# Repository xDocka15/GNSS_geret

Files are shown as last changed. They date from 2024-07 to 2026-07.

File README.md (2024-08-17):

# GNSS_Geret_V1

[3D model](https://github.com/xDocka15/GNSS_geret/blob/main/V1/3D_Print/stl/board.stl)

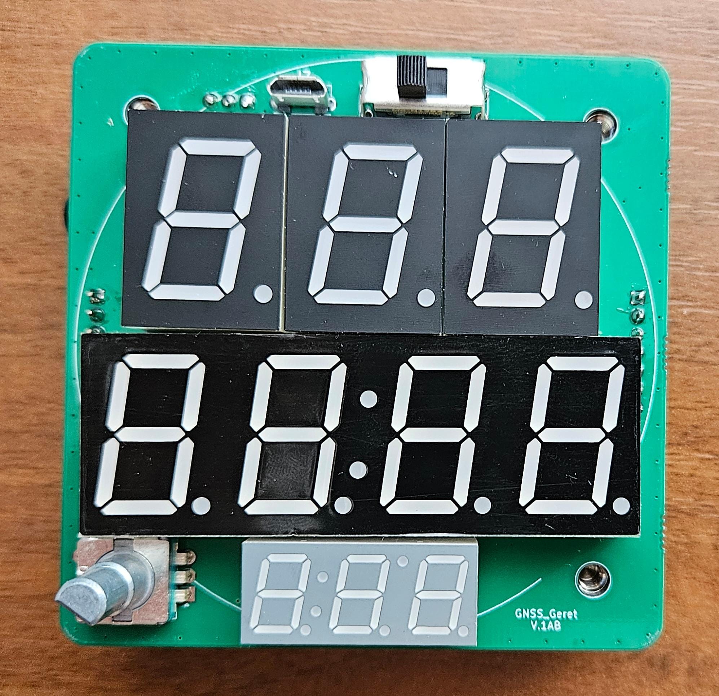
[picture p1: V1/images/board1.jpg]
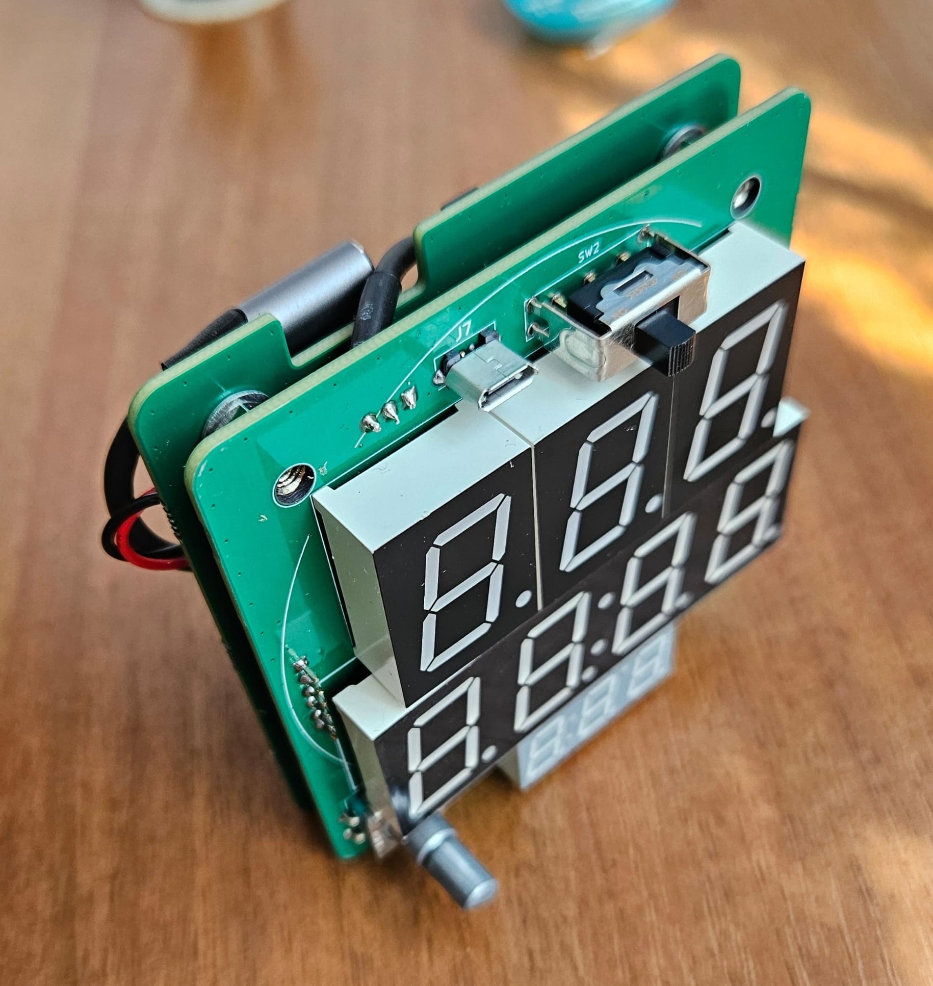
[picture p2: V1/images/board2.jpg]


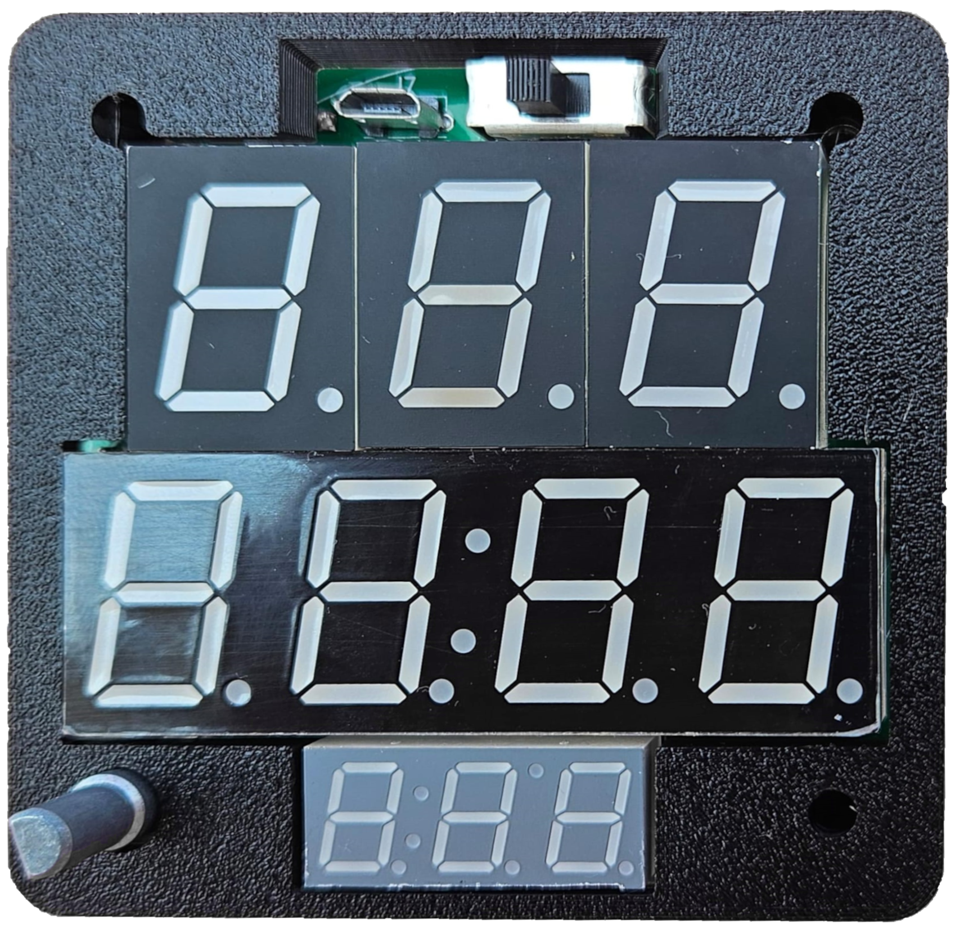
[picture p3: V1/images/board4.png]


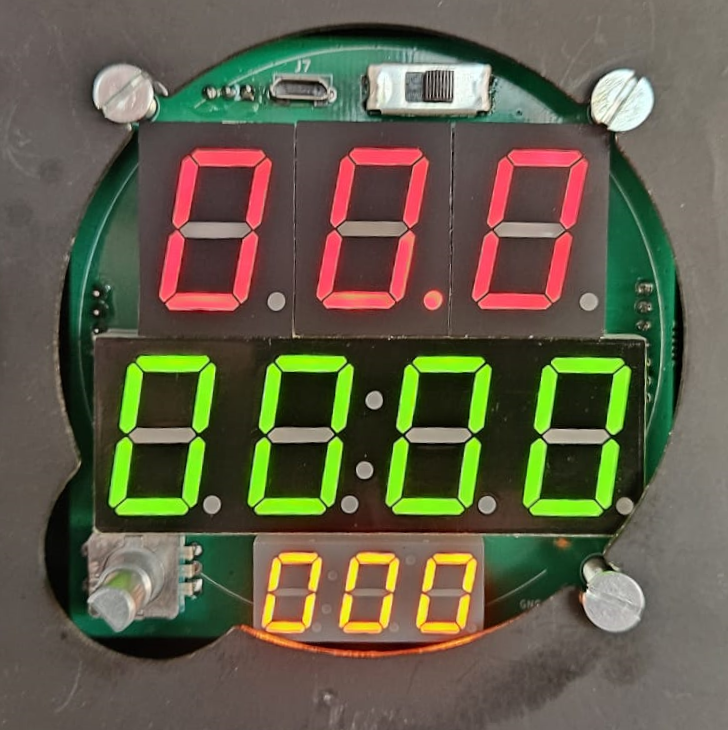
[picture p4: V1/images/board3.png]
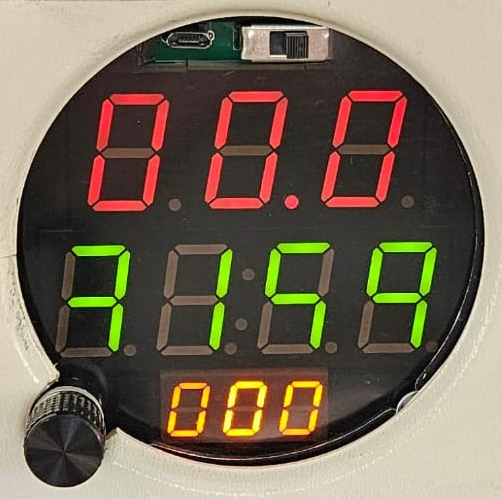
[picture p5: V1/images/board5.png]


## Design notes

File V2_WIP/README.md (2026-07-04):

# Zadanie pre GNSS Geret v2025

Dokument popisuje zmeny/upravy v elektronike gnss-geret z 2024 tak aby vznikla
jednodoskova prenostitelna verzia.

## Strucny opis zmien

Cielom je dosiahnut vyssiu integraciu, mensie rozmery a odstranit nedostatky
z predchadzajucej verzie.

Hlavne zmeny:

* \[x] Z troch DPS zredukovat len na jednu dosku.
* \[X] Povodnu hotovu procesorovu dosku FireBeetle2 nahradit samostatnymi obvodmi
  priamo na DPS a usetrit tym miesto:

  * \[x] Pouzit rovnaky ESP32-WROOM-32E modul
  * \[x] USB/UART prevodnik pre programovanie a ladenie ESP32 aj s DTR+RST pre programovanie
  * \[x] Menic napatia z baterie na 3V3
  * \[x] Nabijaci obvod pre bateriu (lepsi ako na FireBeetle2)

* \[x] Doplnit flash pre zaznam dat.
* \[ ] Lepsia citatelnost displeja s casom.

Vacsina suciastok zostava zachovana, zhodna s verziou v2024.

## Nove suciastky

### ESP32

Zvolit modul:

* ESP32-WROVER-E-N16R8 - trosku vacsi rozmer, ale ma vacsiu pamat, vyvody len z dvoch stran.
* \[x] ESP32-WROOM-32E-N16R2 - mensi rozmer, mensia pamat, vyvody z troch stran.

Umiestnit antenou ku okraju DPS. Pod vstavanou antenou je potrebne odstranit
oblast zeme v jednotlivych vrstvach DPS tak aby nedoslo ku zatieneniu anteny (napr.
vrstvou GND, vid. keepout zone v datasheete). Idealne vyfrezovat z plosaku.

Doska WROVER sa pripajkuje priamo na hlavny DPS.

Nerozpustat obsah WROOM modulu priamo na hlavny DPS, odovodnenie:

* nepredpokladam, ze by sa podarilo dosiahnut vasiu mieru integracie ako samotnemu
  vyrobcovi Espressif - t.j. neusetri sa miesto na DPS
* rucne osadzovanie by bolo skoro nemozne
* vyzadovalo by to ozivit zapojenie aj samotneho procesora
* neskor by ake kolvek chyby mohli mat pricinu bud v osadeni alebo navrhu zapojenia
  procesora

### USB/UART prevodnik

Pouzit niektory z casto pouzivanych USB na UART prevodnikov pre ESP procesory.
Napr. CH340K (bol pouzity aj na FireBeetle2) alebo CP2104, ...

Dolezite je pripojit aj DTR a RTS na GPIO0 a RST aby sa dal procesor uviest do
programovacieho rezimu cez USB.

Inspirovat sa zapojenim podla schemy ku FireBeetle2 alebo napr. ku LiLyGo T-Call.

### SPI Flash

Zapracovat "velku" SPI flash, ktora sa bude pouzivat na zaznam udajov z letu.
Napr. 128Mbit (16MB) [Winbond W25Q128FV](https://www.winbond.com/hq/product/code-storage-flash-memory/serial-nor-flash/?__locale=en&partNo=W25Q128FV).
Pripojit na SPI rozhranie.

* \[x] TODO: vyspecifikovat, na ktore piny procesora pripojit. Ktore z dvoch SPI rozhrani je volne?

### Nabijaci resp. power-management modul

Na napajanie bude pouzity jeden clanok Li-Ion baterie (v letectve sa nepouzivaju Li-Pol).
Mal by obsahovat:

* \[x] moznost vycitat cez komunikaciu (idealne I2C) stav nabijania (miera vybita)
* \[x] coulomb counter na meranie kapacity bateria
* \[x] meranie napatia baterie

Zapracovat modul na sledovanie kapacity LiXy batetie MAX17043.
https://techfun.sk/produkt/max17043-i2c-modul-pre-sledovanie-stavu-baterie-1s/

https://www.sparkfun.com/mikroe-charger-2-click.html
Coulomb counter TC3100 + nabijaci obvod IP5306-I2C.
https://electronics.stackexchange.com/questions/17463/help-on-stc3100-calculations
https://github.com/danirebollo/ArduinoSTC3100

* \[x] TODO: upresnit.

### Tlacidlo

Pridat nove mikro-tlacidlo niekam na pravu prednu stranu.

* \[x] TODO: Vyspecifikovat tlacidlo, umiestnenie a pripojenie.

### Indikacna LED

Pridat SMD modru LED na stranu DPS s displejmi. Pouzije sa na zakladnu indikaciu
a ladenie SW. Spolu s LED na rovnaky ovladaci pin procesora pripojit aj test-pad.
Nakolko su vsetky ostatne LED pripojene len cez komunikacne rozhranie, tato bude
urcite fungovat vzdy.
Zapojit na GPIOxy voci GND.

* \[x] TODO: Urcit, na ktory GPIO pin.

### Senzor osvetlenia

Doplnit senzor osvetlenia a automaticky upravovat jas.
Umiestnit ho do vnutorneho rohu kde sa stretava maly dolny displej a stredny velky displej
na pravej strane (na opacnej ako je encoder, aby sa rukou nezakryl).
V kryte sa na danom mieste urobi vybratie, cez ktore (a cez foliu) bude prenikat okolite svetlo
az ku DPS.

* \[x] TODO: Pouzit jednoduchy fototranzistor? Vyspecifikovat.

## Upravy

Vo verzii v2024 boli na DPS/scheme identifikovane nesledujuce body na zlepsenie:

* \[x] Doplnit USB iface pre gnss (3v3 urovne, pripojit vdd\_usb)
  Zvazit umiestnenie plnohodnotneho USB micro-B konektora otoceneho ku okraju DPS
  kvoli servisnemu pristupu do GNSS modulu. Pouzit uhlovy konektor o 90st zarovnany
  s okrajom DPS. Pristupny bude len po vybrati DPS z krabicky.
* \[x] Pridat odrusovaci kondik na tlacidlo tocitka.

  * TODO: Vyspecifikovat.

* \[x] Na vstup A a B z encodra doplnit pull-up rezistory 10k na 3V3.
* \[x] Do footprintu encodera pridat aj diery pre upevnovacie otvory (pajkovatelne, spojene s GND)
* \[x] Pouzit iny typ stredneho 4-ciferneho displeja:

  * Na v2024 bol pouzity typ so spolocnou anodou (KW4-804AGB).

    * Radic HT16K33 je koncipovany tak, ze:
    * cez samostatne anody dokaze do LED pustit 20mA
    * ces spolocnu katodu dokaze preniest 8x 20mA
    * kvoli tomu nebolo mozne vybudit LED na maximalny jas co sa prejavilo na zlej
      citatelnosti za slnecneho svetla.

  * \[x] Vo v2025 pouzit model so spolocnou katodou (KW4-804CGB).

    * Tomu sa musi prisposobit aj zapojenie jednotlivych segmentov (po vzore maleho displeja).
    * \[x] TODO: vyspecifikovat zapojenie displeja.

* \[x] Pouzit USB-C konektor, zapojenie rovnake ako na FireBeetle2.
* \[x] Ku GNSS modulu pripojit aj zalohovaciu bateriu pre RTC.

### Chybajuce veci

Vo verzii v2024 chybali nasledujuce veci, ktore su aplikovatelne aj na v2025:

* \[x] Na 5V vetvu pridat velky stabilizacny kondik 470u/16V.
* Doplnit oznacenie D2 do schemy.
* \[x] Pridat test pad s GND (na pripojenie sondy multimetra/osciloskopu).

### Navrh DPS

Pri navrhu DPS zohladnit nasledujuce pripomienky:

* \[x] Pri ploskach spojenych s GND nastavit uzsie (tensie) mostiky, ktore prepajaju
  plosku s okolitou "vyliatou" plochou, resp. s vrstvou GND. Pri rucnom pajkovani
  sa cez mensie mostiky odvadza menej tepla do susednej velkej medenej plochy
  a suciastky sa lahsie osadzuju.
* \[x] Popisok konektora dat dalej od samotnej suciastky (aby sa po osadeni nezakryl).
* \[x] Zvacsit diery pre hlavny vypinac (bolo treba zbrusit z pinov).

  * \[x] TODO: diery pre kontakty alebo upevnovacie diery?

* \[x] Mensie diery pre kolikove konektory (ak budu pouzite, boli volne a dali sa osadit krivo :)
* \[x] Doplnit popisky ku test-padom "TPx" aby sa dali lahsie sparovat so schemou.
* \[ ] Pri vyrobe pouzit ciernu farbu plosaku, nie zelenu. Cierne pozadie zlepsi
  citatelnost 7-seg displejov.
* \[x] Niektore TP presunut ku okrajom DPS, tak aby boli dostupne z oboch stran DPS
  a neboli zakryte suciastkami (napr. displejmi):

  * TP6 (5V)
  * TPxy (3V3, pridat)
  * TPxy (GND, pridat)

* \[x] Antenny konektor moze byt bud SMA alebo U.FL (IPEX)

  * Na DPS cez seba prekryt plosky pre oba typy konektorov
  * Vid. footprint: https://meshtastic.org/assets/images/t-beam-sx1262-3dc0a8d2d866b06b04a457567063e034.webp
  * Bud sa osadi SMA konektor (uhlovy alebo priamy) alebo sa osadi U.FL konektor
    a antena sa zabuduje priamo do skatulky.

* Pri rozmiestnovani suciastok je mozne umiestnit niektore aj pod maly dolny
  displej z TOP strany.

  * Aby bol displej v rovine s RGB displejmi, musi byt osadeny co najdalej od DPS.
  * Tym vznikne pod displejom pohodlny priestor pre SMD rezistory, kondiky, atp...

    * \[ ] TODO: zmerat vzdialenost od DPS po display.

## Mechanicke upravy

* Zachovat rozostup aj velkosti montaznych dier v troch rohoch.

  * Pouziju sa bud na uchytenie do pristrojoveho panela v lietadle alebo na
    uchytenie krabicky.

* Ine montazne diery nebudu potrebne. Bateria sa osadi do drziaka v krabicke.
* Zachovat umiestnenie antenneho konektora GPS na okraji plosaku aby sa mohol
  pouzit aj uhlovy konektor a externa antena.

# Pripomienky k v2024

Releventnost nasledujuce pripomienok ku verzii v2024 a ich aplikovatelnost aj na
verziu v2025 treba posudit jednotlivo. Niektore mozu byt pouzite aspon ako inspiracia
pre finalnu kontrolu DPS pred odoslanim do vyroby.

* Chyba popisok "U8" pre prislusnu suciastku na DPS
* Popisky DP a DM na J3 nie su rovnakym smerom
* Roztec ESP pinheaderov je mala, nesuhlasi s ESP doskou. Zapichnuta kolikova lista
  sa roztiahne ako vejar.
* nejednoznacne ozn. pre D a C (co som tym myslel?)
* kvoli zahnutemu kablu USB-C na ESP doske posunut ESP dosku o 7mm do lava
  a presunut J4 dole na uroven RST tlacitka (na ESP doske)
  a otocit orientaciu J4 smerom hore
* USB konektor pre GNSS dat dalej od ANT1 kvoli pristupu.

# Poznamky/Uvahy

* \[ ] V pripade zabudovania v lietadle a pripojenia ku palubnej sieti bude potrebny
  dodatocny obvod s:

  * menicom napatia z 12/24V na 5V
  * elektronickou poistkou

# Pripomienky k v2026

# pripomienky/navrhy

**26.6.2026**
Telefonicky konzultovane pripomienky: 

- [x] Upgradovat projekt na KiCAD v10?
- [x] Doplnit barometer na I2C linku 
  - https://eu.mouser.com/ProductDetail/Bosch-Sensortec/BMP581?qs=Li%252BoUPsLEntPL9tlFmcgXg%3D%3D
  - umiestnit na top stranu medzi encoder a maly display (do stredu aby bolo dost miesta na teplovzdusne osadenie)
  - CSB pripojit priamo na VDDIO (zvolit I2C)
  - SDO pripojit na GND
  - INT zapojit na TestPad
  - treba zaradit 10Ohm odpor do serie s VDD a VDDIO?
- [x] Na spolocne katody oboch 7seg displejov DS1 (CC1, CC2, CC3, CCL123) a U402 (CC11, CC22. CC33, CC44) doplnit 0Ohm odpor 0603 (mozno sa pouzije na zrovnanie intenzity stredneho a dolneho 7seg displeja, kedze zdielaju jeden driver a spolocne ovladanie intenzity)
- [x] Zvazit otocenie U103 o 90st v proti smere hodinovych ruciciek (bodka bude hore v pravo, Y+ bude smerovat hore)
  - len ak to nebude prilis komplikovane, je mozne kompenzovat smer osi v SW
- [x] Flash U102 zamenit za iny model a ine puzdro, napajanie 2.7-3.3V: 
  - pouzit male puzdro WSON-8 8x6mm (velkostou sa zhoduje s SOIC8 povodne pouzitej W25Q128JV)
    - Winbond W25N02KVZEIR 2Gb (256MB) (Mouser ma na sklade):
      - https://eu.mouser.com/ProductDetail/Winbond/W25N02KVZEIR-TR?qs=YwPsRIUVAOcmpACOC6b95Q%3D%3D
    - Winbond W25N04KVZEIR 4Gb (512MB) (Mouser nema na sklade) 
      - https://eu.mouser.com/ProductDetail/Winbond/W25N04KVZEIR?qs=YwPsRIUVAOdveyibmg1m8Q%3D%3D
  - existuje aj velke SOIC16 puzdro (s dobrou dostupnostou na Mousri) ale to je prilis objemne:
    - https://eu.mouser.com/ProductDetail/Winbond/W25N02KVSFIR?qs=W%2FMpXkg%252BdQ4KUHHgPqoidQ%3D%3D
    - W25N02KVSFIR 2Gb
    - zmesti sa na miesto povodne SOIC8 ak by sa posunul U103 hore?
    - existuje aj mensia kapacita 1Gb: W25N01GVSFIG
- [x] U602 GND pripojit najskor ku R_E605 a az potom ku GND vrstve, vid AppNote strana 4: The STC3100's ground connection (GND) is used as the reference input for the current measurement and must be connected to the ground side of the sense resistor by a dedicated track.
- [x] Ku R_E605 doplnit poznamku, ze jeho hodnota musi splnat: `Rcg <= 0.08/peak_current_A` a `33mOhm => peak +/-2A`.
- [x] U602 pripojit natrvalo ku baterii. Vypinac dat az za U602. 
  - [x] VIN pripojit priamo na bateriu (aj s filtrom).
  - [x] Doplnit SMD jumper, ktorym sa VCC pripoji bud na VIN (pred vypinacom) alebo na BATT (za spinacom)
    - NIE, VCC bude pripojeny stale na bateriu pred vypinacom aby sa zachoval obsah internej RAM
  - Odber obvodu je len 100uA, bude udrzovat stav pocitadiel v internej RAM aj pri vypnutom ESP co zjednodusi sw.
- [x] Nastavit inu I2C adresu pre display driver U4 
  - signaly A0,A1,A2 (ROW2-0) pripojit cez odpory 39kOhm a cez jednu spolocnu diodu ku pinu AD (COM0), vid datasheet
  - jeden z odporov sa osadi tak aby sa zabranilo kolizii adries s CoulombCounterom
- [x] Ku R_E601 pridat TestPad na stranu ku pinu KEY
- GPS U401: 
  - VDD_USB je pouzite nie na napajanie ale na zistenie pritomnosti USB, musi byt urovne 3V3, odber je cca 1mA
  - [x] Pridat jednosmerny level shifter z 5V na 3V3, ktory sa pripoji na VDD_USB cez pull down rezistor 10kOhm + 1uF kondenzator 
    - Alebo pouzit LDO tak ako na vzorovej GNSS7CLICK doske (AP7331)
  - [x] do serie s USB_DP/M pridat rezistor 27 Ω 5% 0.1W (vid vzor GNSS7CLICK)
  - [x] 1uF kondenzator hned vedla VCC pinu
  - skontrolovat layout DPS pre VCC pin a RF_IN pin podla NEO-M9N_Integrationmanual_UBX-19014286.pdf strana 81 https://content.u-blox.com/sites/default/files/NEO-M9N_Integrationmanual_UBX-19014286.pdf
  - [x] EXTINT vytiahnut na TestPad
  - [x] pin Reset vytiahnut na TestPad
- [x] Su niekde v plosaku "slepe prekovy"? T.j. take co nejdu napriec celym plosakom ale len od vonkajsej po niektoru vnutornu vrstvu? 
  - Nemali by sme mat, predrazilo a skomplikovalo by to vyrobu. Na nasom plosaku by sa tomu malo dat vyhnut.
  - NIE, KiCad taketo prepoje by default nerobi
- [x] Prekovy v ploskach urcenych pre rucne osadzovanie sa daju prezit. Ale pri strojovom osadzovani by do nich vtahovalo cin a potom by nozicka nebola pripajkovana (skusenosti z roboty). Idealne ak by prekovy boli mimo padov - aspon pre sucsiastky, ktore maju potencial na strojove osadzovanie (t.j. tie, ktore sa tazko osadzuju rucne).
  - Pokusit sa presunut prekovenia tam kde sa to da. Pri zvysnych prekovoch sa spolahneme, ze sa pri vyrobe PCB (cez JLC PCB) upchaju diery a nebudu stahovat cin.
- [x] Prekovy mimo pajkovacich ploch prekryt nepajivou maskou (farbou). Hlavne tie, ktore su blizko pajkovatelnych ploch (aby do nich nevtahovalo cin a suciastku)
  - KiCad to tak robi by default
- Doplnit menic z externeho zdroja 12-30V na 5V/3A 
  - Externe napajanie bude privedene cez konektor, asi cez Zeleny Konektor - este upresnit !!!
- [x] Ku TP7 doplnit popisok "3V3"
- [x] Ku TP103 doplnit popisok "5V"
- [x] Odstranit popisok "+5V" pri C406
- [x] Doplnit popisky s vyznamom LED: D101 "3V3", D102:"5V", D103:"VUSB"
- [x] Do schemy ku jednotlivym IO z ESP doplnit popisok s vyznamom: (podobne ako tam uz je SCK, MOSI, ...) 
  - IO0: RTS
  - IO2: LED
  - IO4: SEL_FL
  - IO12: TP12
  - IO13: RGB_DATA
  - IO14: PULSE
  - IO15: SW2
  - IO16: GNSS TX
  - IO17: GNSS RX
  - IO25: ENC SW
  - IO26: ENC CLK
  - IO27: ENC DT
  - IO32: SEL_IMU
  - IO35: LIGHT_SENS
- [x] Ku R_E605 doplnit "1%"
- [ ] Ku J601 doplnit typ konektora (PH2.0?)
  - zistit typ podla konektora na baterii
- [x] Doplnit externy PullUp rezistor na IO5 (vyber modu pri bootovani)
- [x] Kozmeticke upravy v scheme: 
  - Strana6: Premiestnit odkaz na USB a BATT na najblizsiu krizovatku cesticiek s bodkou
- [x] Ku kazdemu I2C cipu pridat jeho adresu:
  - `0xEA` BatteryCharger
  - `0x70` CoulombCounter
  - `0x71-7` DisplayDriver, nastavuje sa cez ROW0-2
  - `0x46` Baro
  - `0x44` Lux meter
  - `0x14` Magnetometer
- [x] Vsade na DPS doplnit popisky s oznacenim (nazvom) suciastok
- [x] Doplnit snimac svetla na I2C zbernicu OPT3001 alebo OPT3004DTSR (package SOT-5X3)
  - umiestnit blizko fotorezistora
  - pin ADDR pripojit na GND
- [x] Overit, ci staci 600mA na 3V3 pre ESP aj GNSS aj ostatne obvody?
  - Na prvom gerete bol rovnaky zdroj 600mA
  - Pribudli nove obvody (baro, flash, imu, magnetometer)
- Vymenit nabijaci cip za USBC-PD, ktory poskytuje nabijanie 1S LiXX clanku

# Dokoncit:

- ???

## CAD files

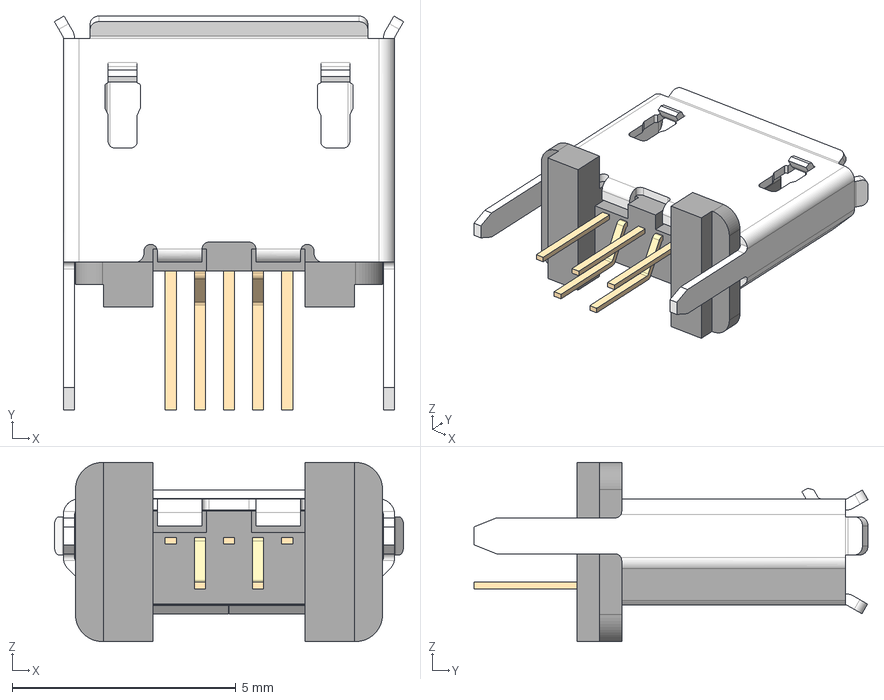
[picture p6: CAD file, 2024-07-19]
V2_WIP/3D/LIB_USB3145-30-1-A/USB3145-30-1-A/3D/USB3145-30-1-A.stp
7.80 x 8.80 x 4.00 mm
USB3145-30-1-A_PART7
USB3145-30-1-A_PART6
USB3145-30-1-A_PART5
USB3145-30-1-A_PART4
USB3145-30-1-A_PART3
USB3145-30-1-A_PART2
USB3145-30-1-A_PART1

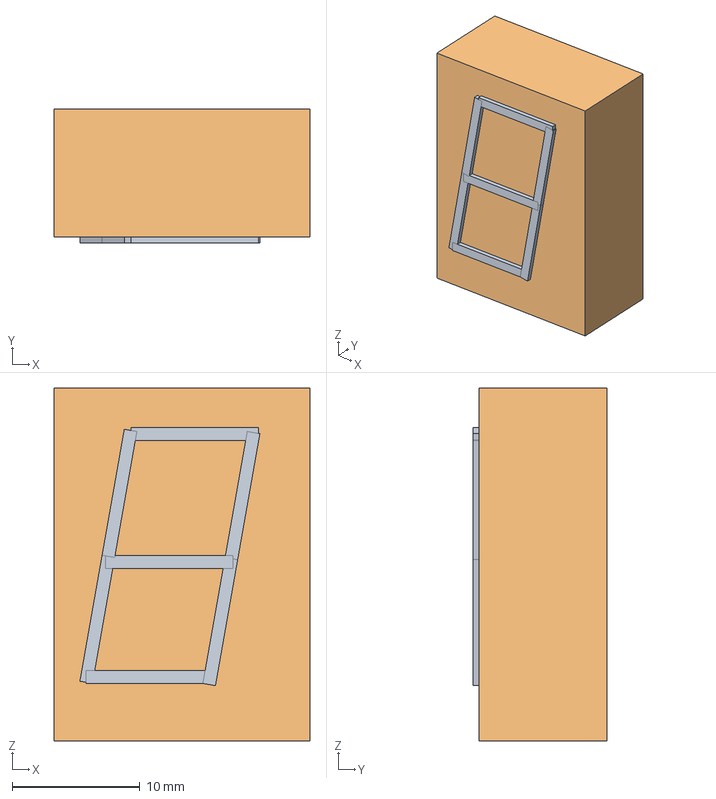
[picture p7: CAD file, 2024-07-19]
V2_WIP/3D/RGB-7seg.step
20.0 x 10.5 x 27.6 mm

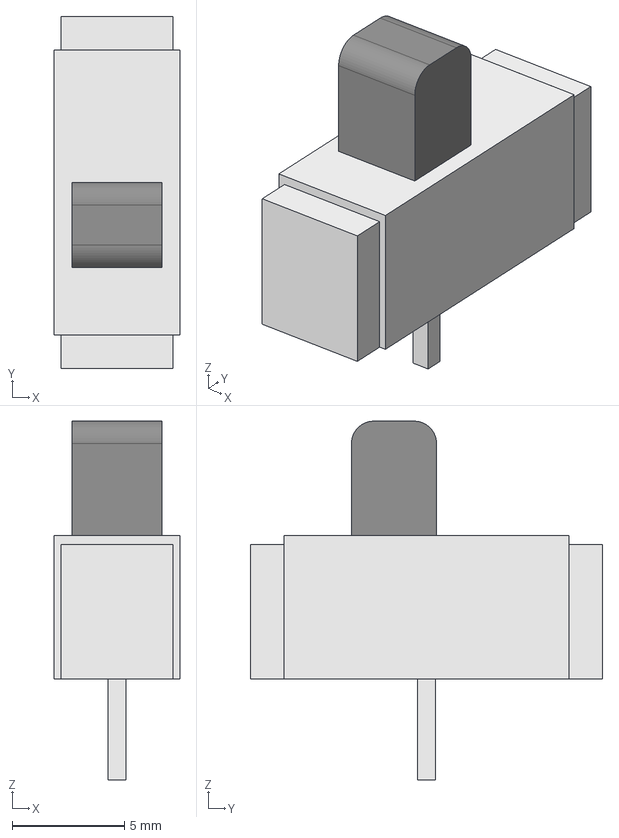
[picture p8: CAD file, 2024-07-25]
V2_WIP/3D/Switch/Switch.step
5.60 x 15.7 x 16.0 mm

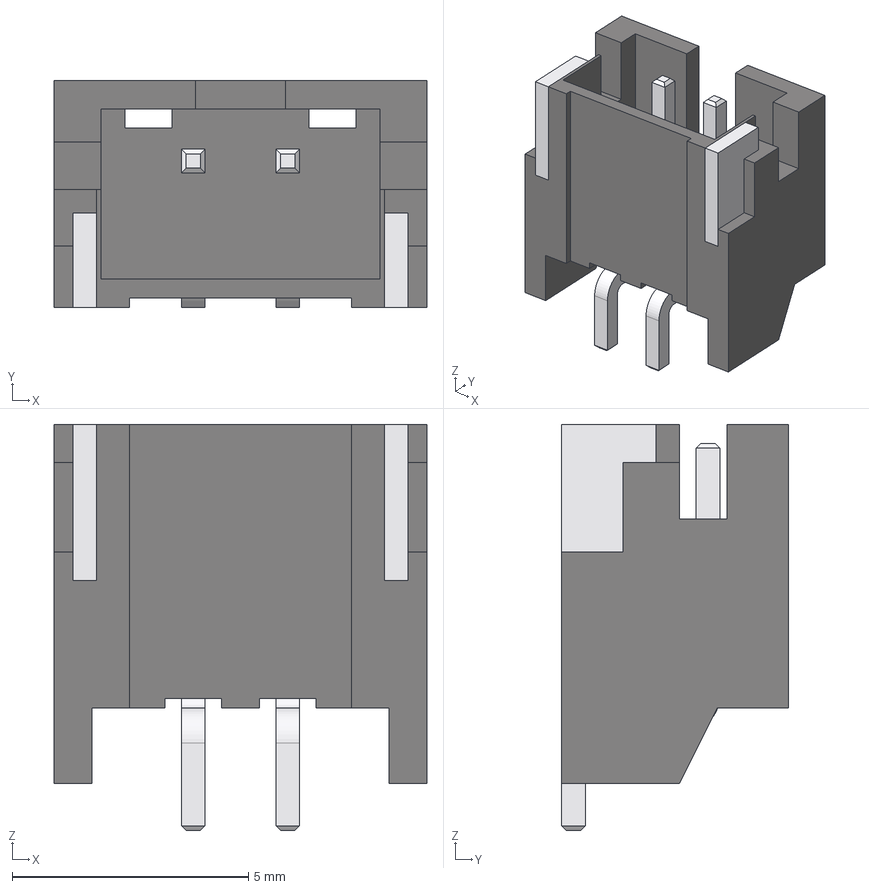
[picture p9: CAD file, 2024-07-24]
V2_WIP/footprints/LIB_1769/1769/3D/1769.stp
7.90 x 4.80 x 8.60 mm

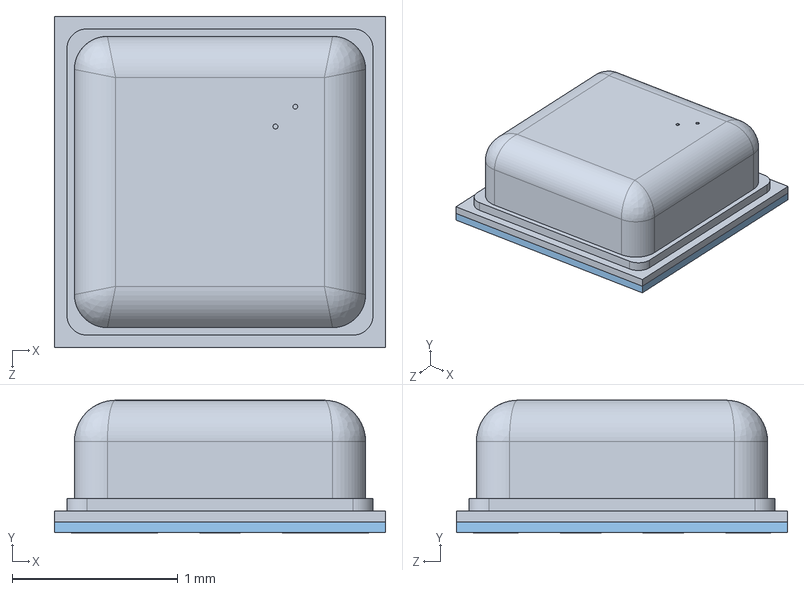
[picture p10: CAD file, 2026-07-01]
V2_WIP/footprints/LIB_BMP581/3D/BMP581.stp
2.00 x 0.801 x 2.00 mm

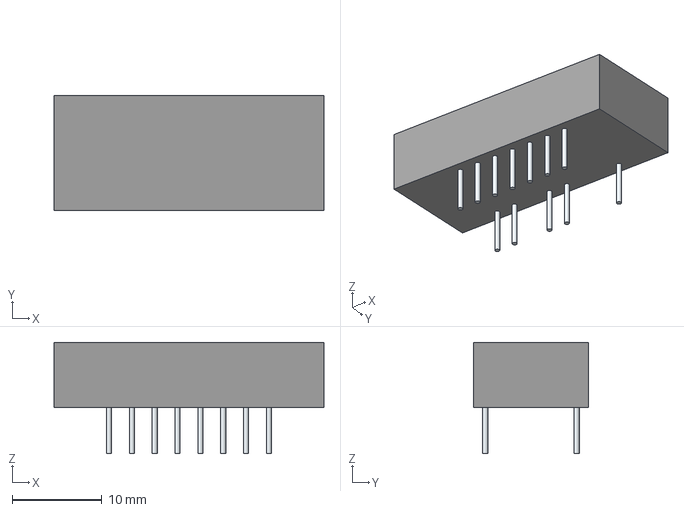
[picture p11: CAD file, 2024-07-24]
V2_WIP/footprints/LIB_LTC-4724JF/LTC-4724JF/3D/LTC-4724JF.stp
30.0 x 12.8 x 12.3 mm
Leads

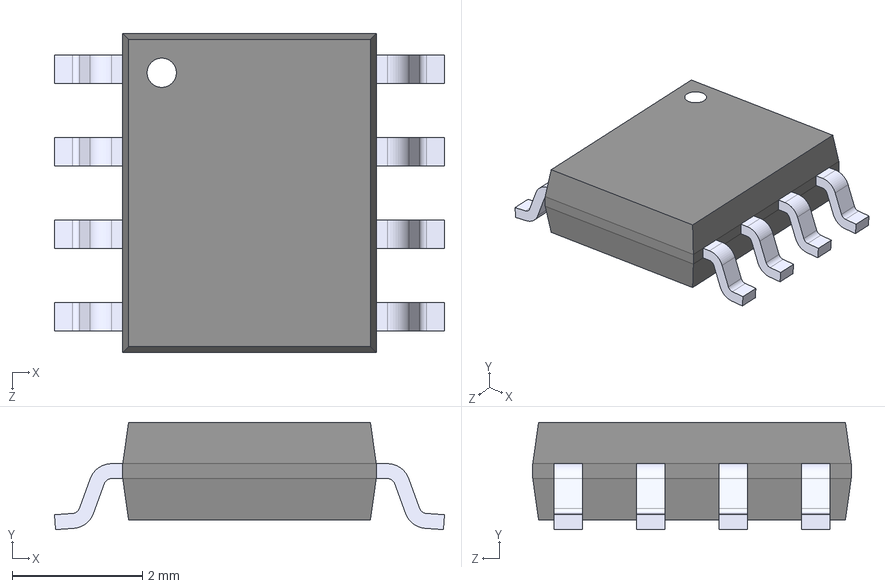
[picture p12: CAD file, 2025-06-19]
V2_WIP/symbols/IP5306/IP5306.step
6.00 x 1.65 x 4.90 mm

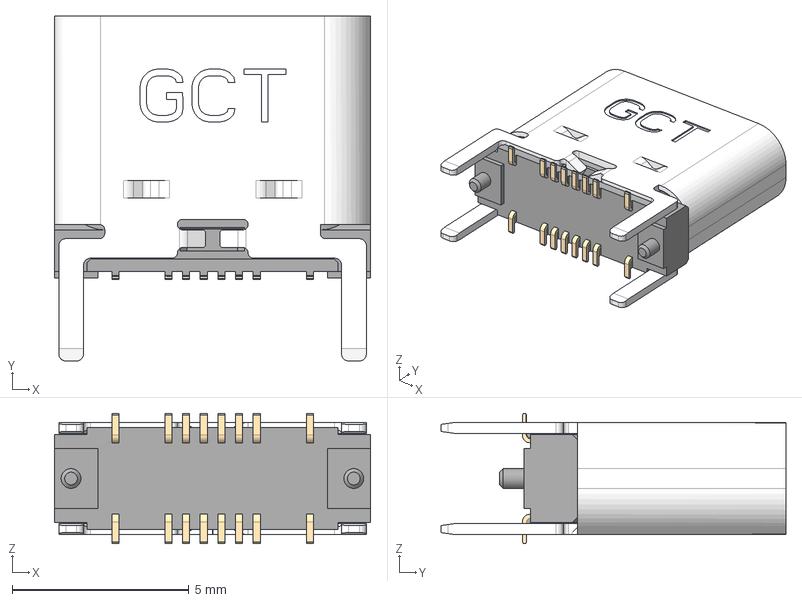
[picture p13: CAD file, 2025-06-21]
V2_WIP/symbols/LIB_USB4145-03-0230-C/USB4145-03-0230-C/3D/USB4145-03-0230-C.stp
8.95 x 9.76 x 3.69 mm
USB4145-03-0230-C_PART2
USB4145-03-0230-C_PART1

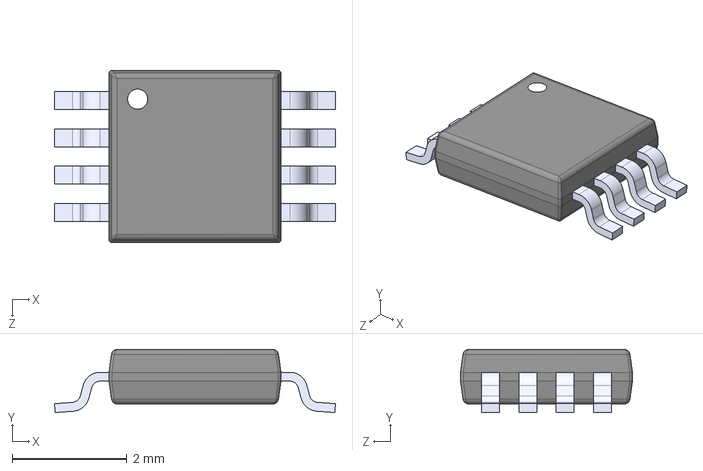
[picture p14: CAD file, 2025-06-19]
V2_WIP/symbols/STC3100IST/STC3100IST.step
4.90 x 1.10 x 3.00 mm

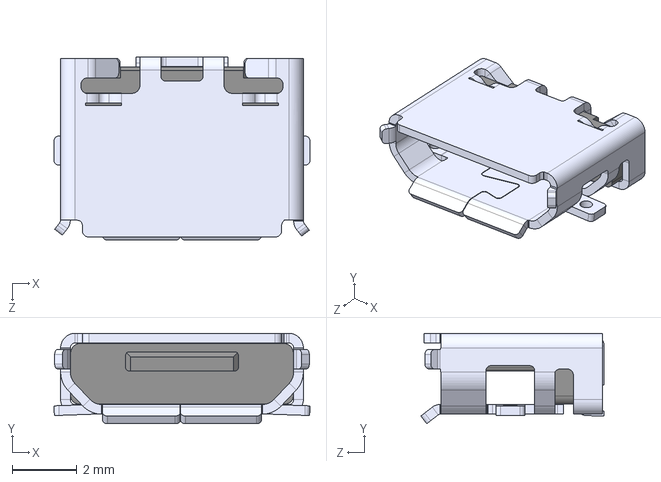
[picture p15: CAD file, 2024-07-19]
V2_WIP/3D/10118192-0001LF/10118192-0001LF.step
7.91 x 2.79 x 5.67 mm

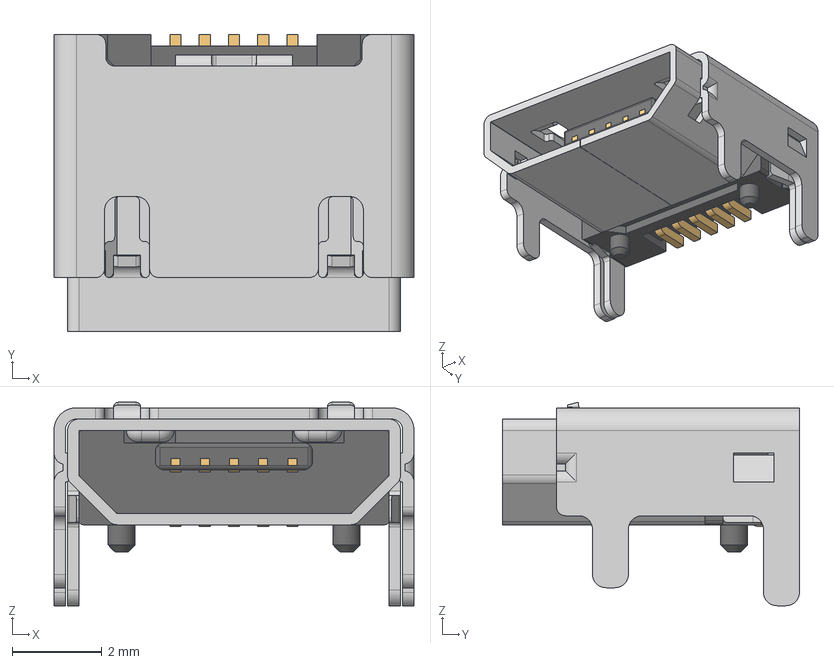
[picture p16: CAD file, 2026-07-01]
V2_WIP/footprints/LIB_629105150521/629105150521/3D/629105150521.stp
8.00 x 6.60 x 4.52 mm
629105150521_Housing
629105150521_Pin1 x 4
629105150521_Pin2
629105150521_Shielding2
629105150521_Shielding

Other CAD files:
V2_WIP/3D/RGB-7seg.FCStd
V2_WIP/3D/Switch/Switch.FCStd

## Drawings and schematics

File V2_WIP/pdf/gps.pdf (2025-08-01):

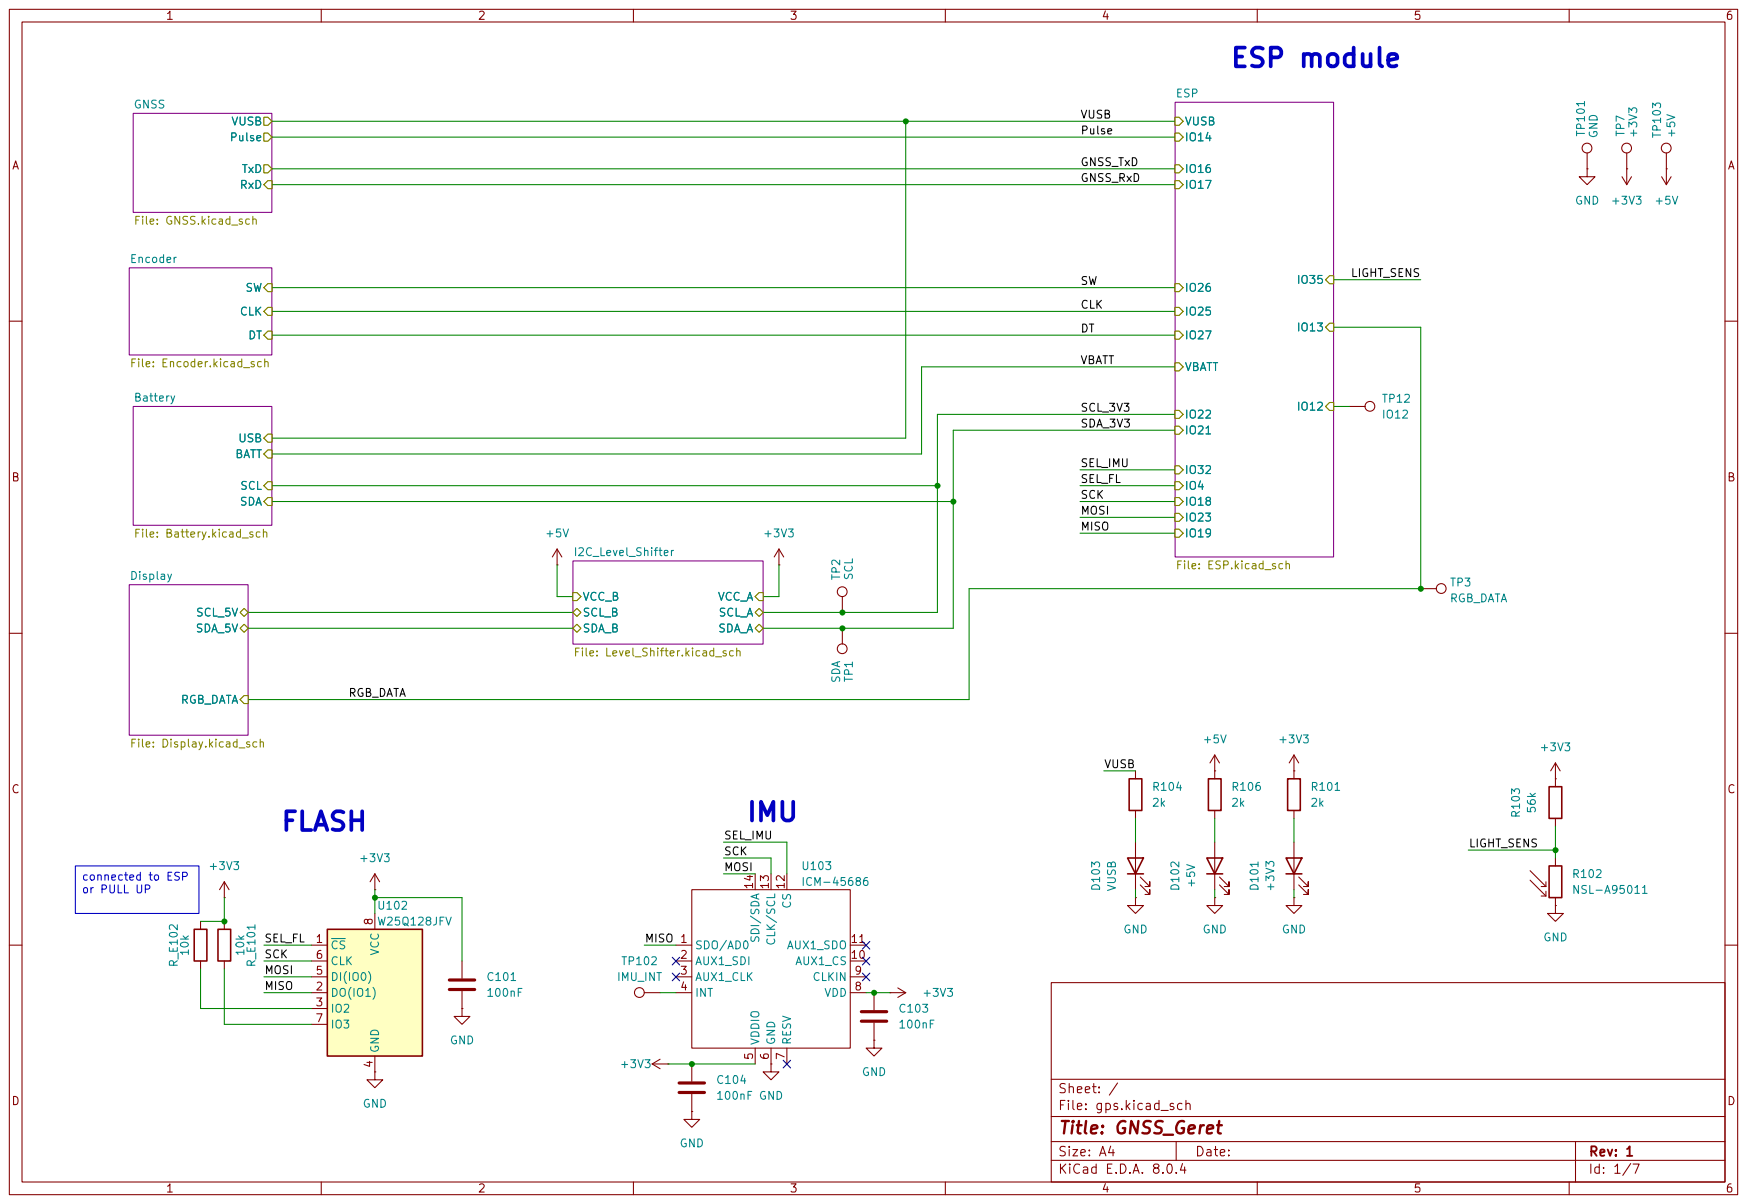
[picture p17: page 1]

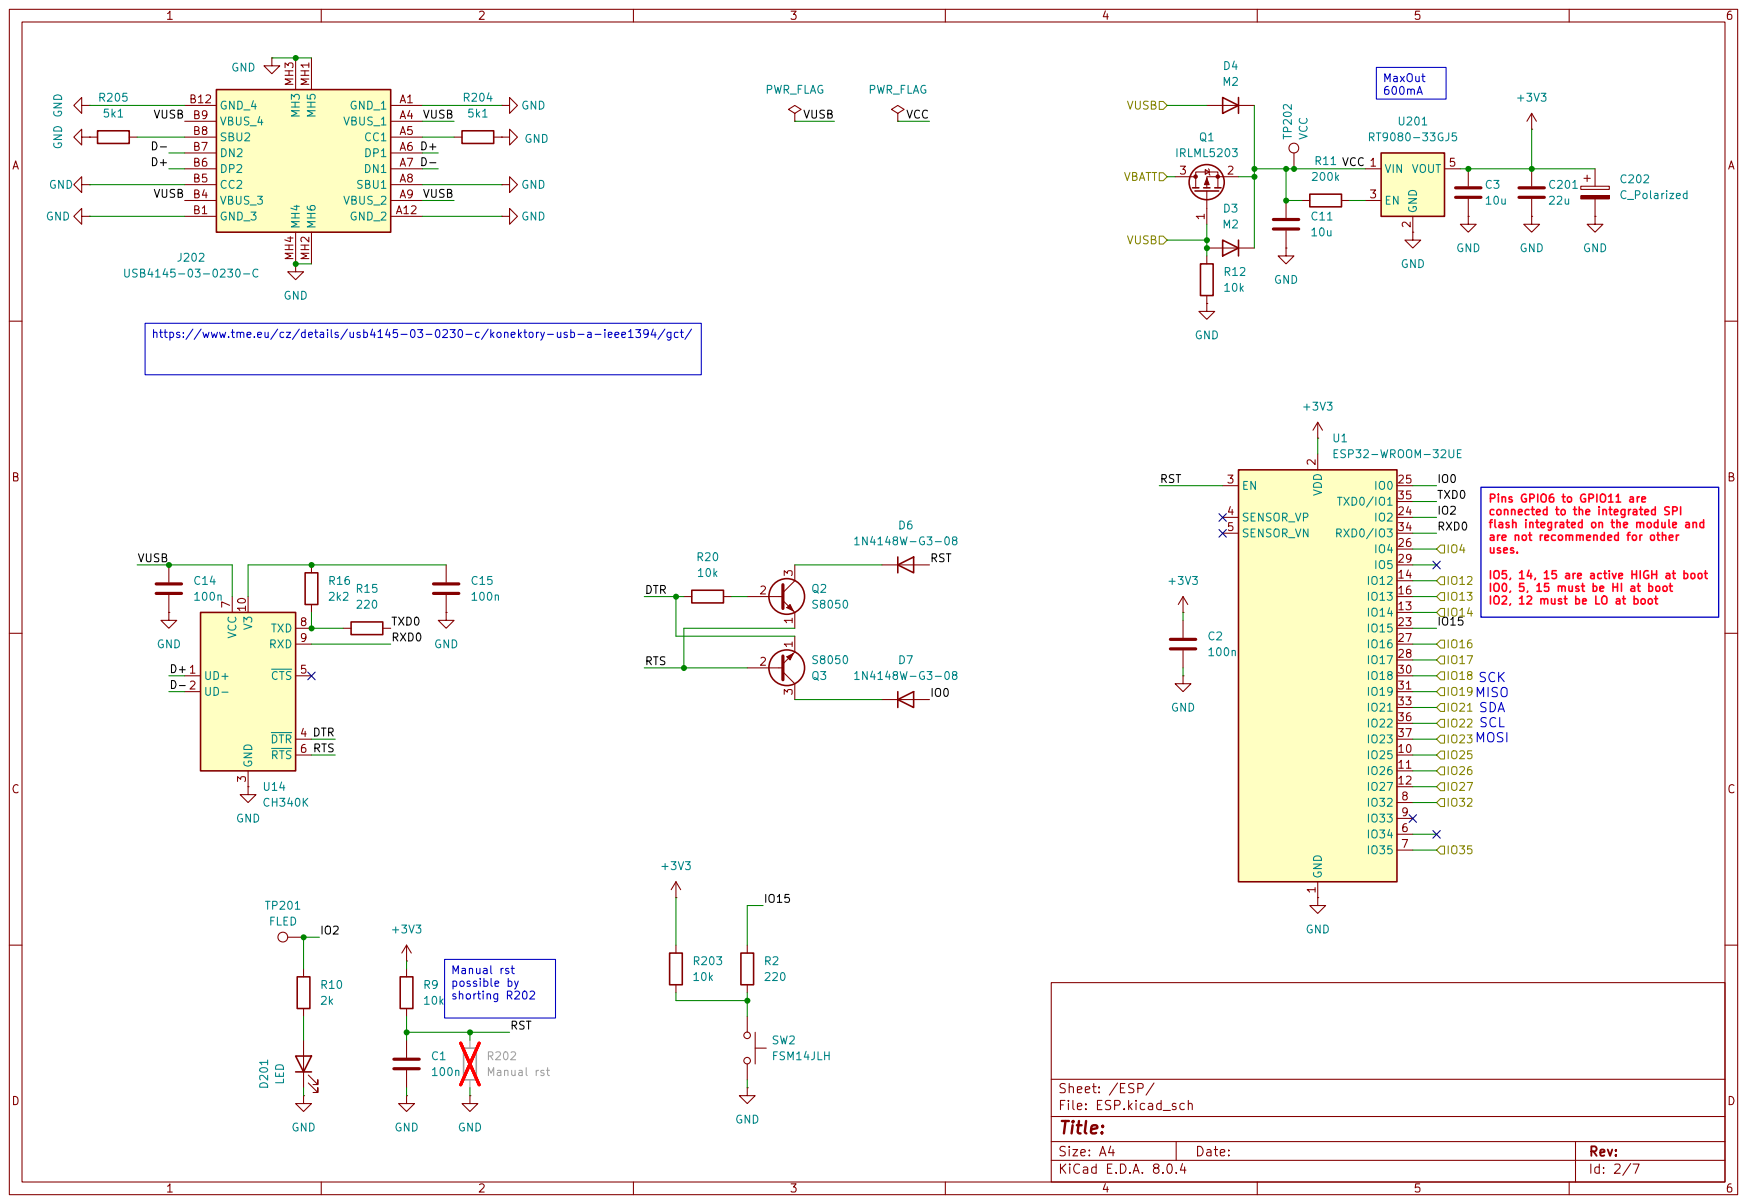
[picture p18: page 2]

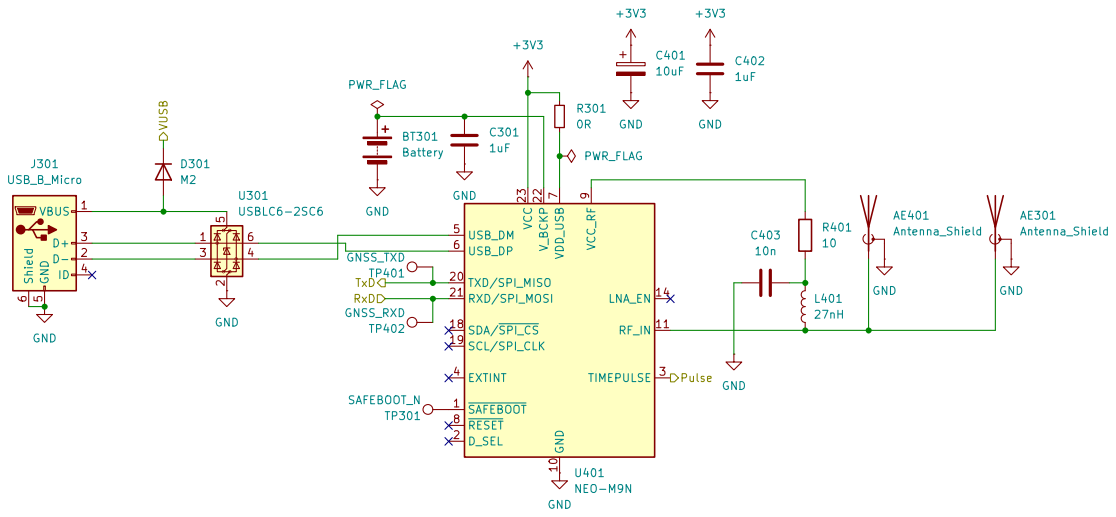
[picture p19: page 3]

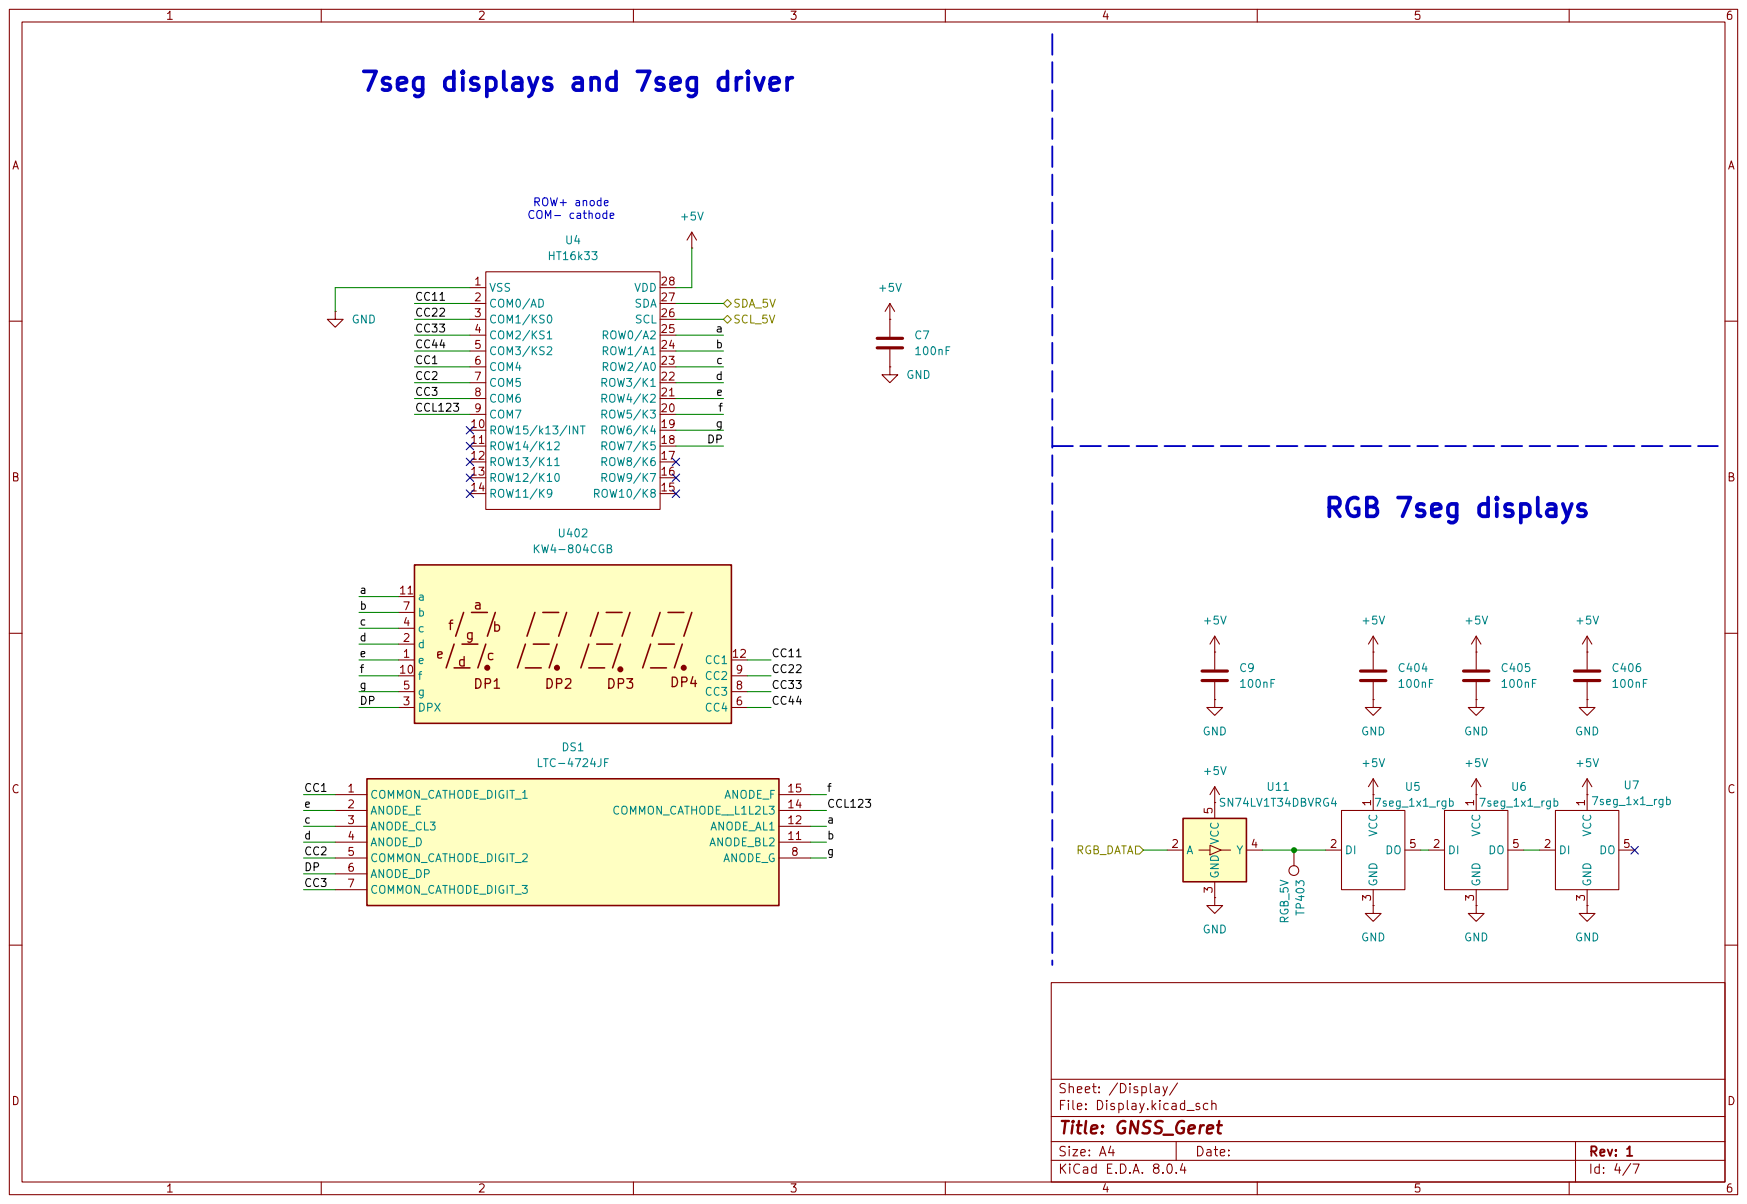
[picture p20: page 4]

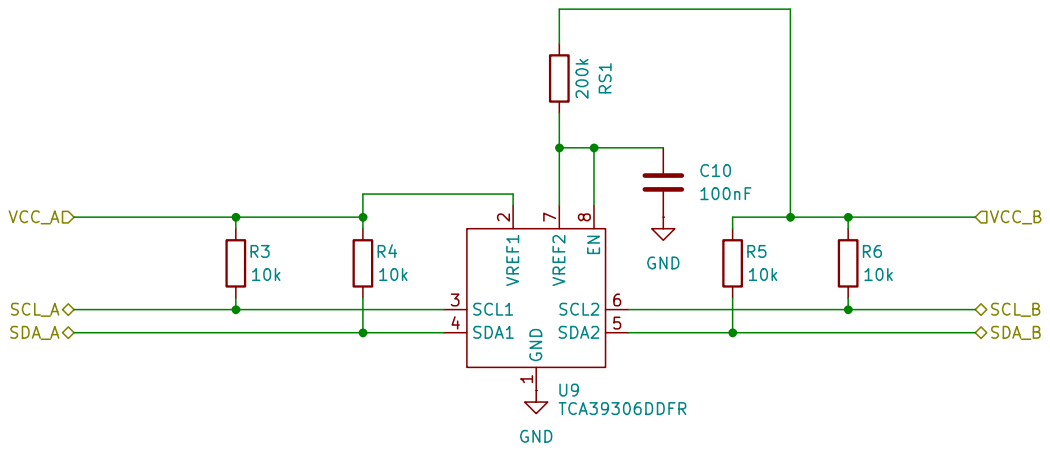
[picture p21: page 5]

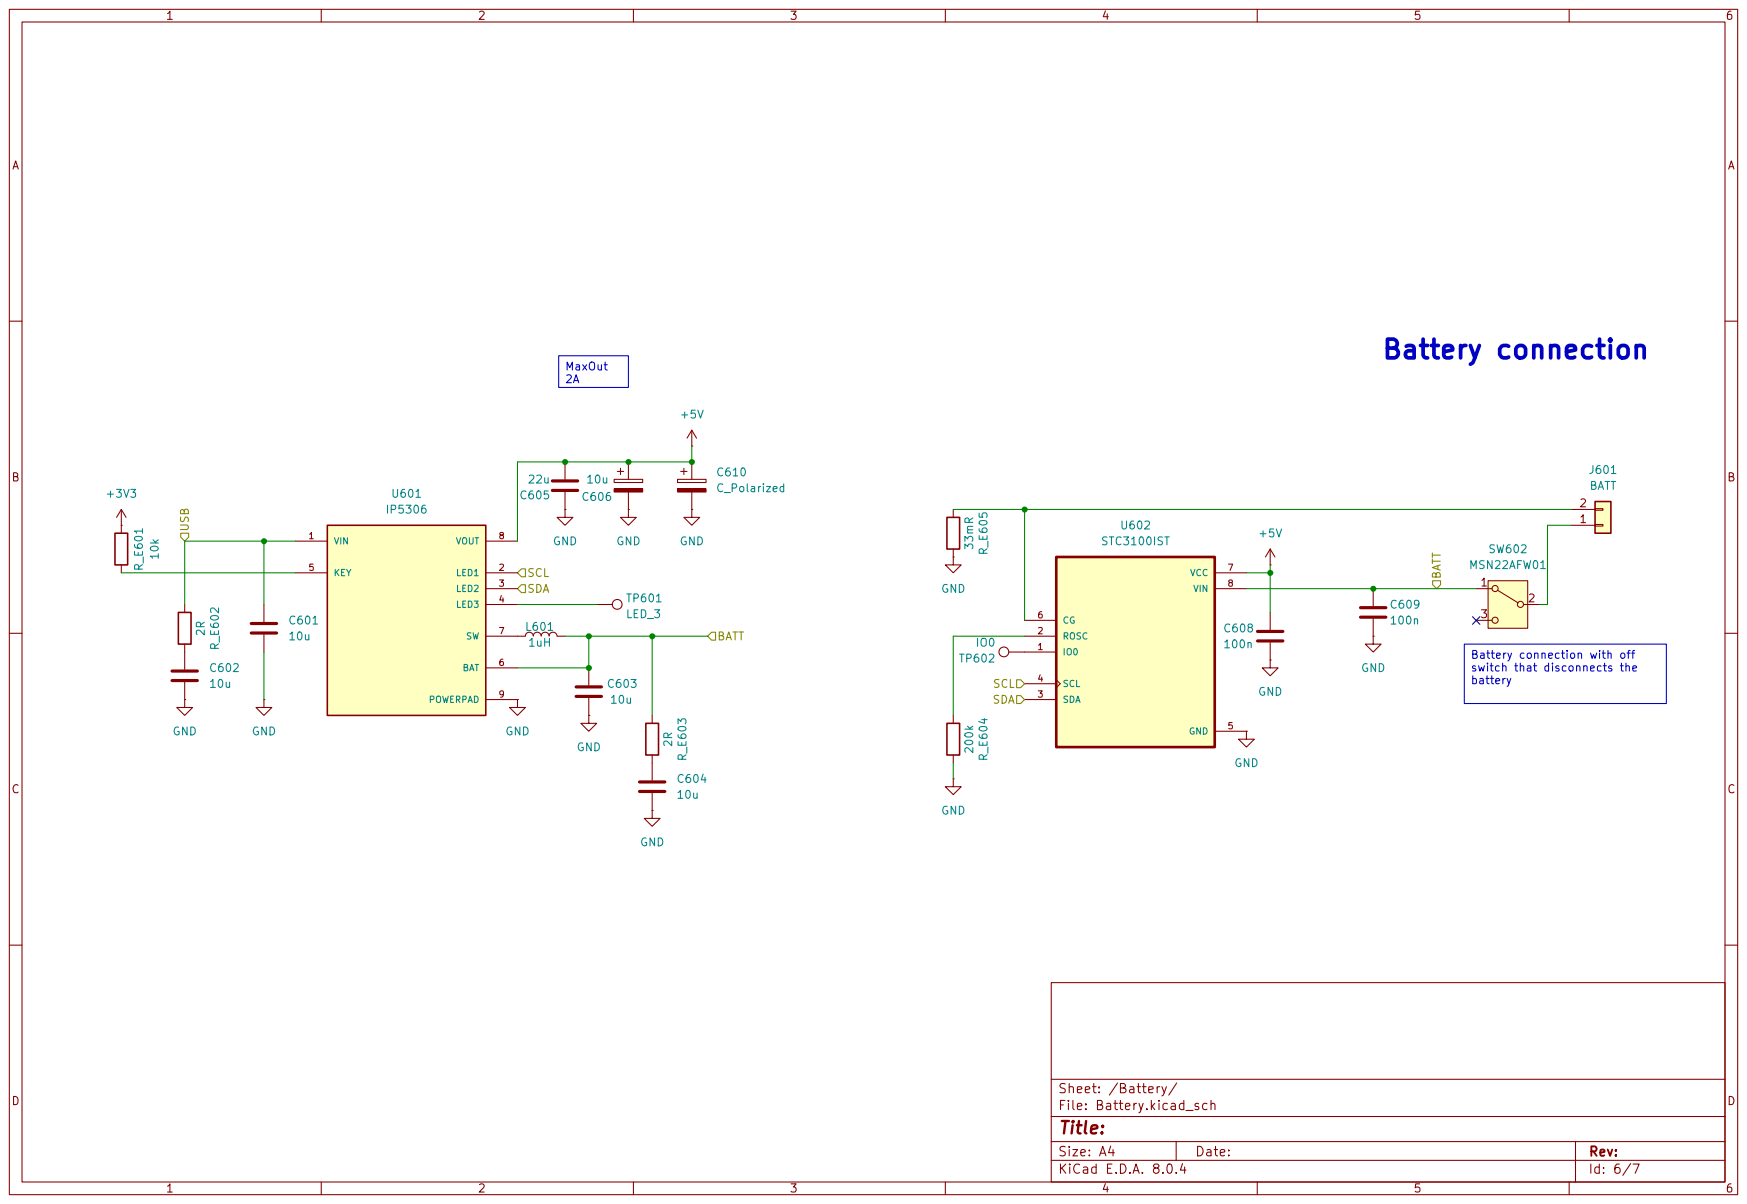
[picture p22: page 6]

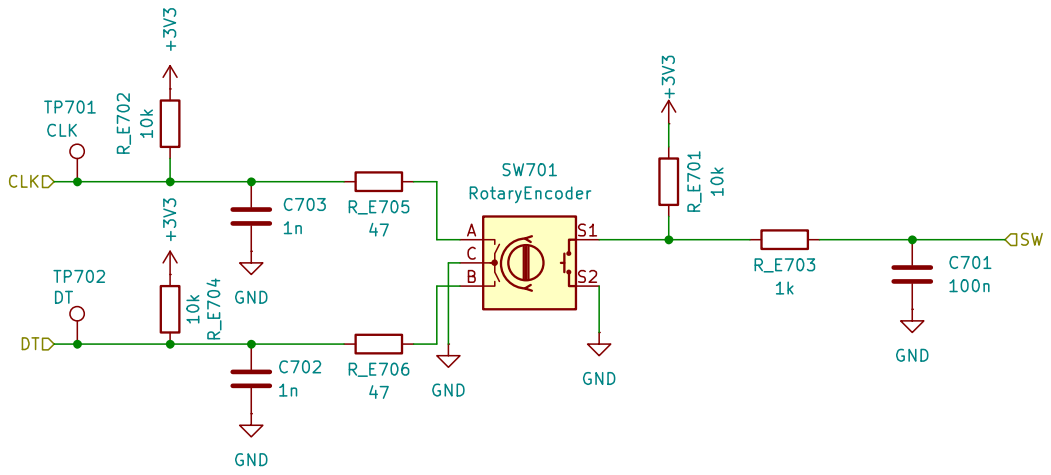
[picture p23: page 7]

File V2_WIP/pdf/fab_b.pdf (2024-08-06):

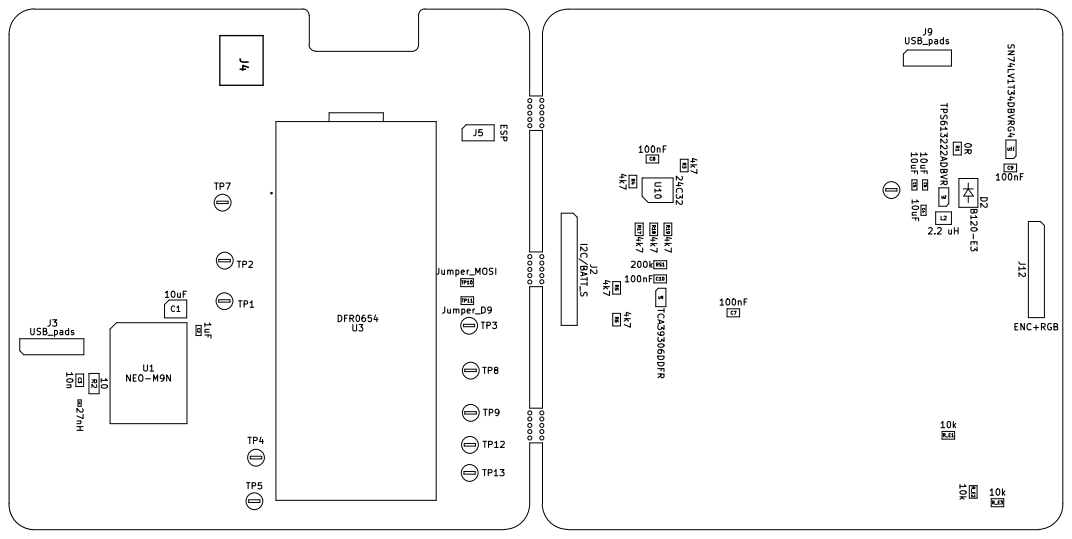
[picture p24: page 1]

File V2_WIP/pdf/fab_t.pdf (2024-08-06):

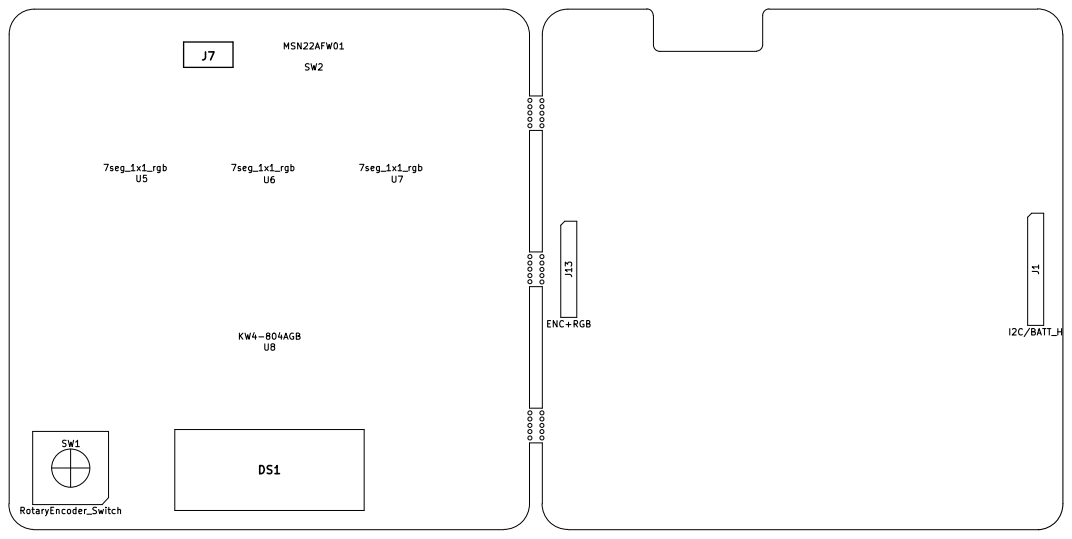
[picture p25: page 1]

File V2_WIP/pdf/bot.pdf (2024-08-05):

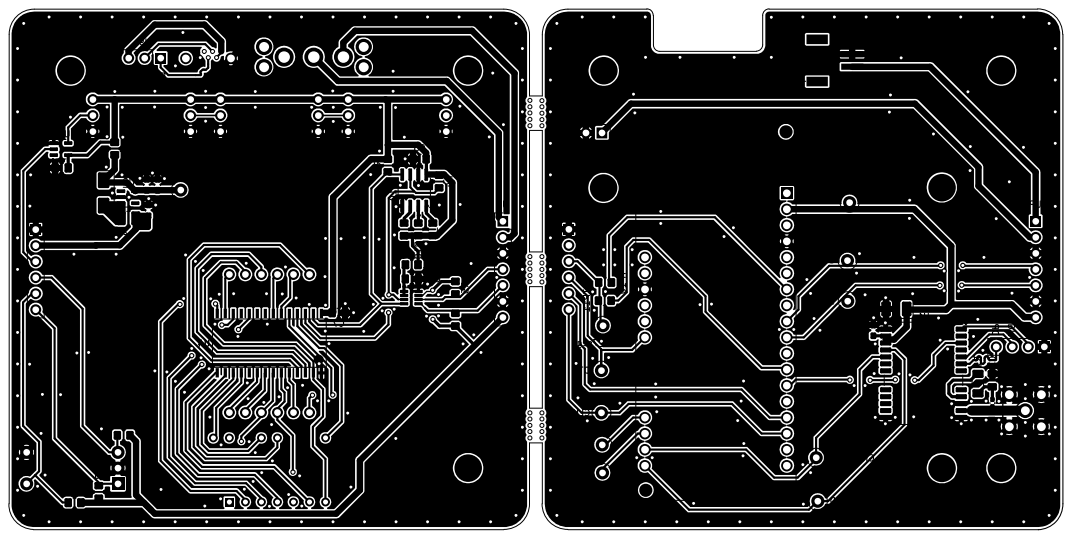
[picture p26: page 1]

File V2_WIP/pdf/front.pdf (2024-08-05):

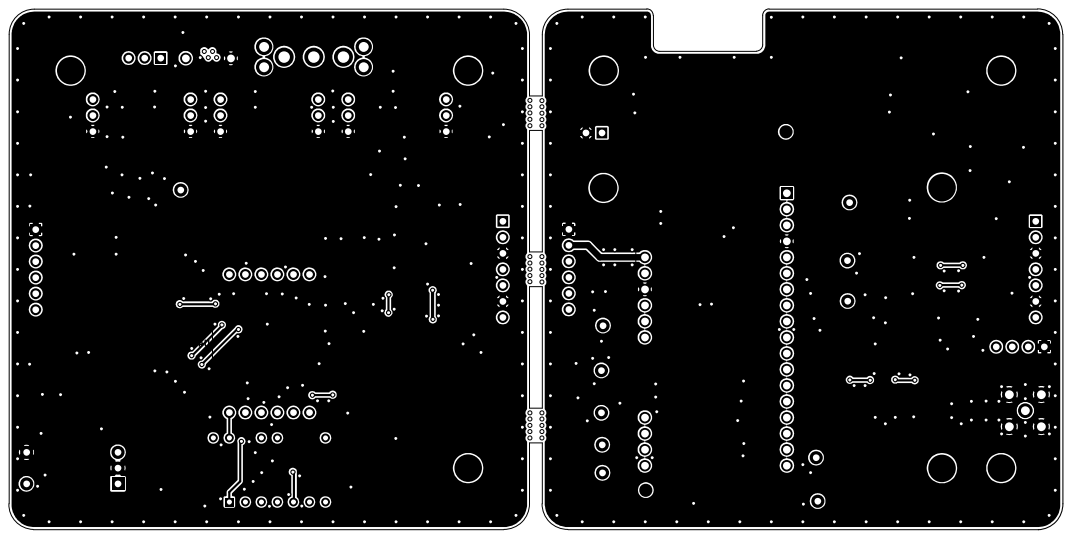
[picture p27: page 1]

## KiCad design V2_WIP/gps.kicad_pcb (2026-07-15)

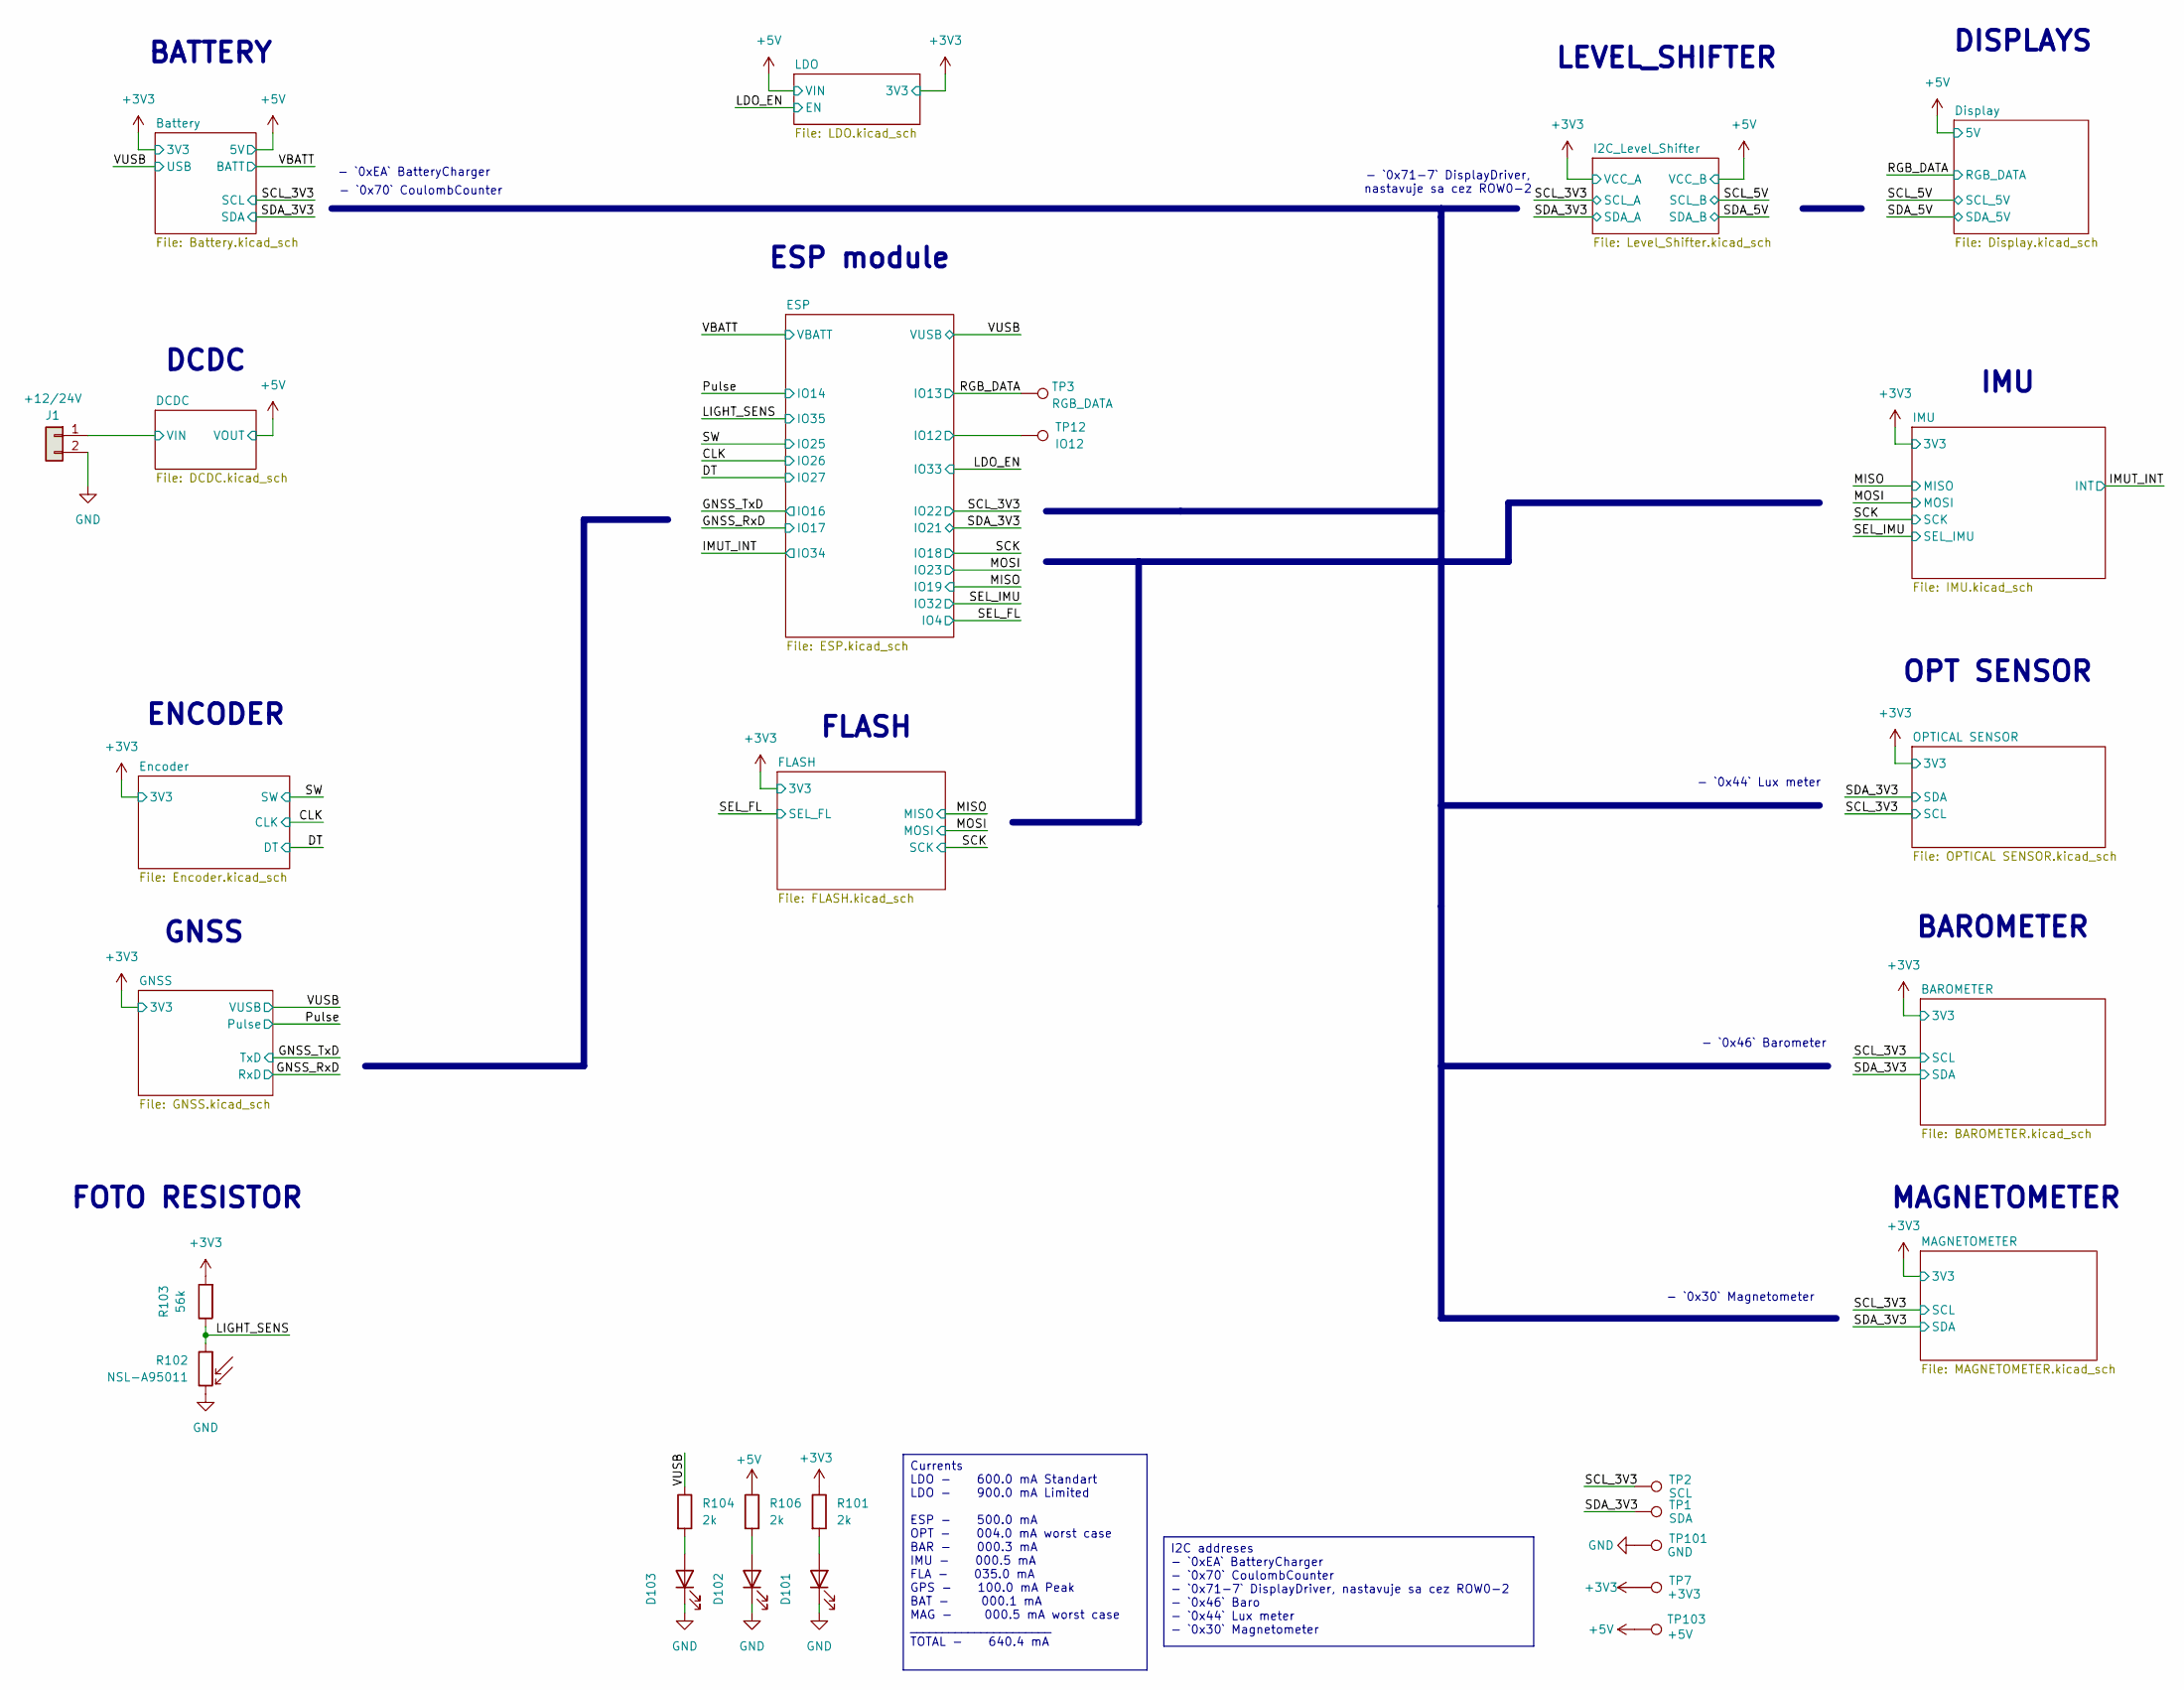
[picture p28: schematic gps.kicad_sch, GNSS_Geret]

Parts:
D101, D102, D103: D_0603_1608Metric_Pad1.05x0.95mm_HandSolder
J1: +12/24V; PhoenixContact_GMSTBVA_2,5_2-G-7,62_1x02_P7.62mm_Vertical
R101, R104, R106: 2k; R_0603_1608Metric_Pad0.98x0.95mm_HandSolder
R102: NSL-A95011; R_LDR_5.1x4.3mm_P3.4mm_Vertical
R103: 56k; R_0603_1608Metric_Pad0.98x0.95mm_HandSolder
TP1: SDA; TestPoint_Pad_D1.0mm
TP2: SCL; TestPoint_Pad_D1.0mm
TP3: RGB_DATA; TestPoint_Pad_D1.0mm
TP7: +3V3; TestPoint_Pad_D1.0mm
TP12: IO12; TestPoint_Pad_D1.0mm
TP101: GND; TestPoint_THTPad_D2.5mm_Drill1.2mm
TP103: +5V; TestPoint_Pad_D1.0mm

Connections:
+3V3: R101.1, R103.2, TP7.1 (1_1); also elsewhere on the board
+5V: R106.1, TP103.1 (1_1); also elsewhere on the board
/DCDC/VIN: J1.1; also elsewhere on the board
/ESP/IO12: TP12.1 (1_1); also elsewhere on the board
/LIGHT_SENS: R102.1, R103.1; also elsewhere on the board
/RGB_DATA: TP3.1 (1_1); also elsewhere on the board
/SCL_3V3: TP2.1 (1_1); also elsewhere on the board
/SDA_3V3: TP1.1 (1_1); also elsewhere on the board
/VUSB: R104.1; also elsewhere on the board
GND: D101.1 (K), D102.1 (K), D103.1 (K), J1.2, R102.2, TP101.1 (1_1); also elsewhere on the board
unnamed: D101.2 (A), R101.2
unnamed: D102.2 (A), R106.2
unnamed: D103.2 (A), R104.2

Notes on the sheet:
ESP module
- `0x44` Lux meter
BATTERY
GNSS
DCDC
OPT SENSOR
MAGNETOMETER
FOTO RESISTOR
FLASH
DISPLAYS
- `0xEA` BatteryCharger
- `0x71-7` DisplayDriver, nastavuje sa cez ROW0-2
- `0x46` Barometer
BAROMETER
- `0x70` CoulombCounter
- `0x30` Magnetometer
ENCODER
LEVEL_SHIFTER
IMU
Currents LDO - 600.0 mA Standart LDO - 900.0 mA Limited ESP - 500.0 mA OPT - 004.0 mA worst case BAR - 000.3 mA IMU - 000.5 mA FLA - 035.0 mA GPS - 100.0 mA Peak BAT - 000.1 mA MAG - 000.5 mA worst case ______________________ TOTAL - 640.4 mA
I2C addreses - `0xEA` BatteryCharger - `0x70` CoulombCounter - `0x71-7` DisplayDriver, nastavuje sa cez ROW0-2 - `0x46` Baro - `0x44` Lux meter - `0x30` Magnetometer

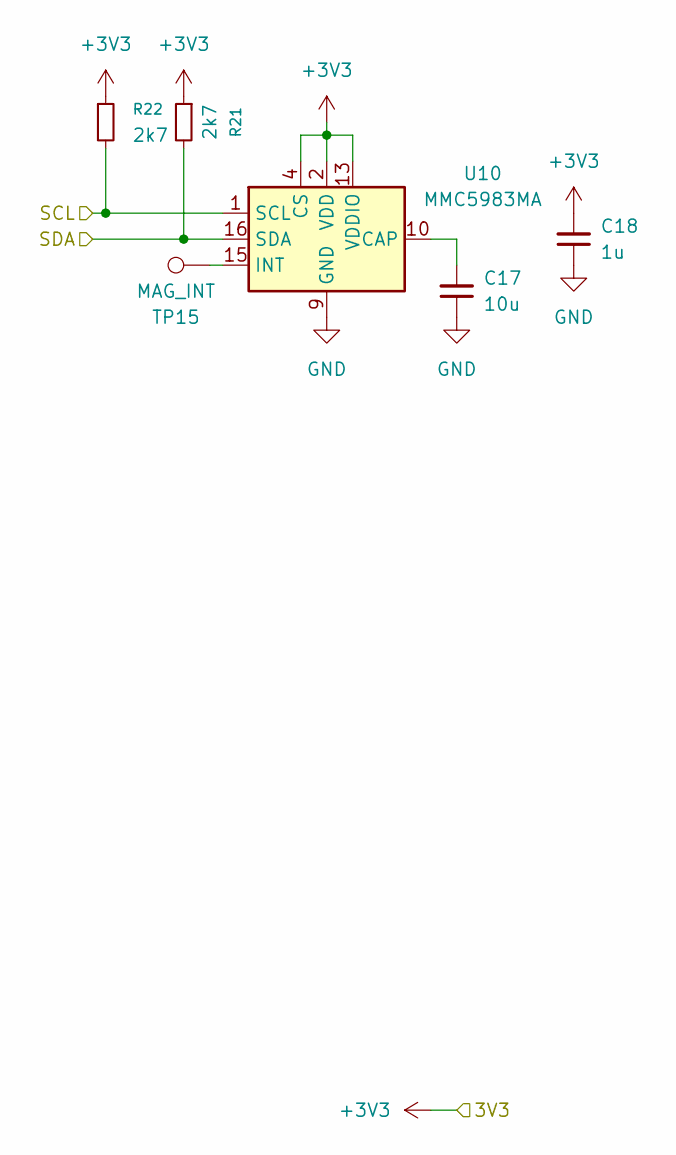
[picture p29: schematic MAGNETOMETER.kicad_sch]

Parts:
C17: 10u; C_0603_1608Metric_Pad1.08x0.95mm_HandSolder
C18: 1u; C_0603_1608Metric_Pad1.08x0.95mm_HandSolder
R21, R22: 2k7; R_0603_1608Metric_Pad0.98x0.95mm_HandSolder
TP15: MAG_INT; TestPoint_Pad_D1.0mm
U10: MMC5983MA; LGA-16_3x3mm_P0.5mm

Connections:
+3V3: C18.2, R21.1, R22.1, U10.2 (VDD), U10.4 (CS), U10.13 (VDDIO); also elsewhere on the board
/SCL_3V3: R22.2, U10.1 (SCL); also elsewhere on the board
/SDA_3V3: R21.2, U10.16 (SDA); also elsewhere on the board
GND: C17.1, C18.1, U10.9 (GND), U10.11 (GND); also elsewhere on the board
unnamed: C17.2, U10.10 (CAP)
unnamed: TP15.1 (1_1), U10.15 (INT)

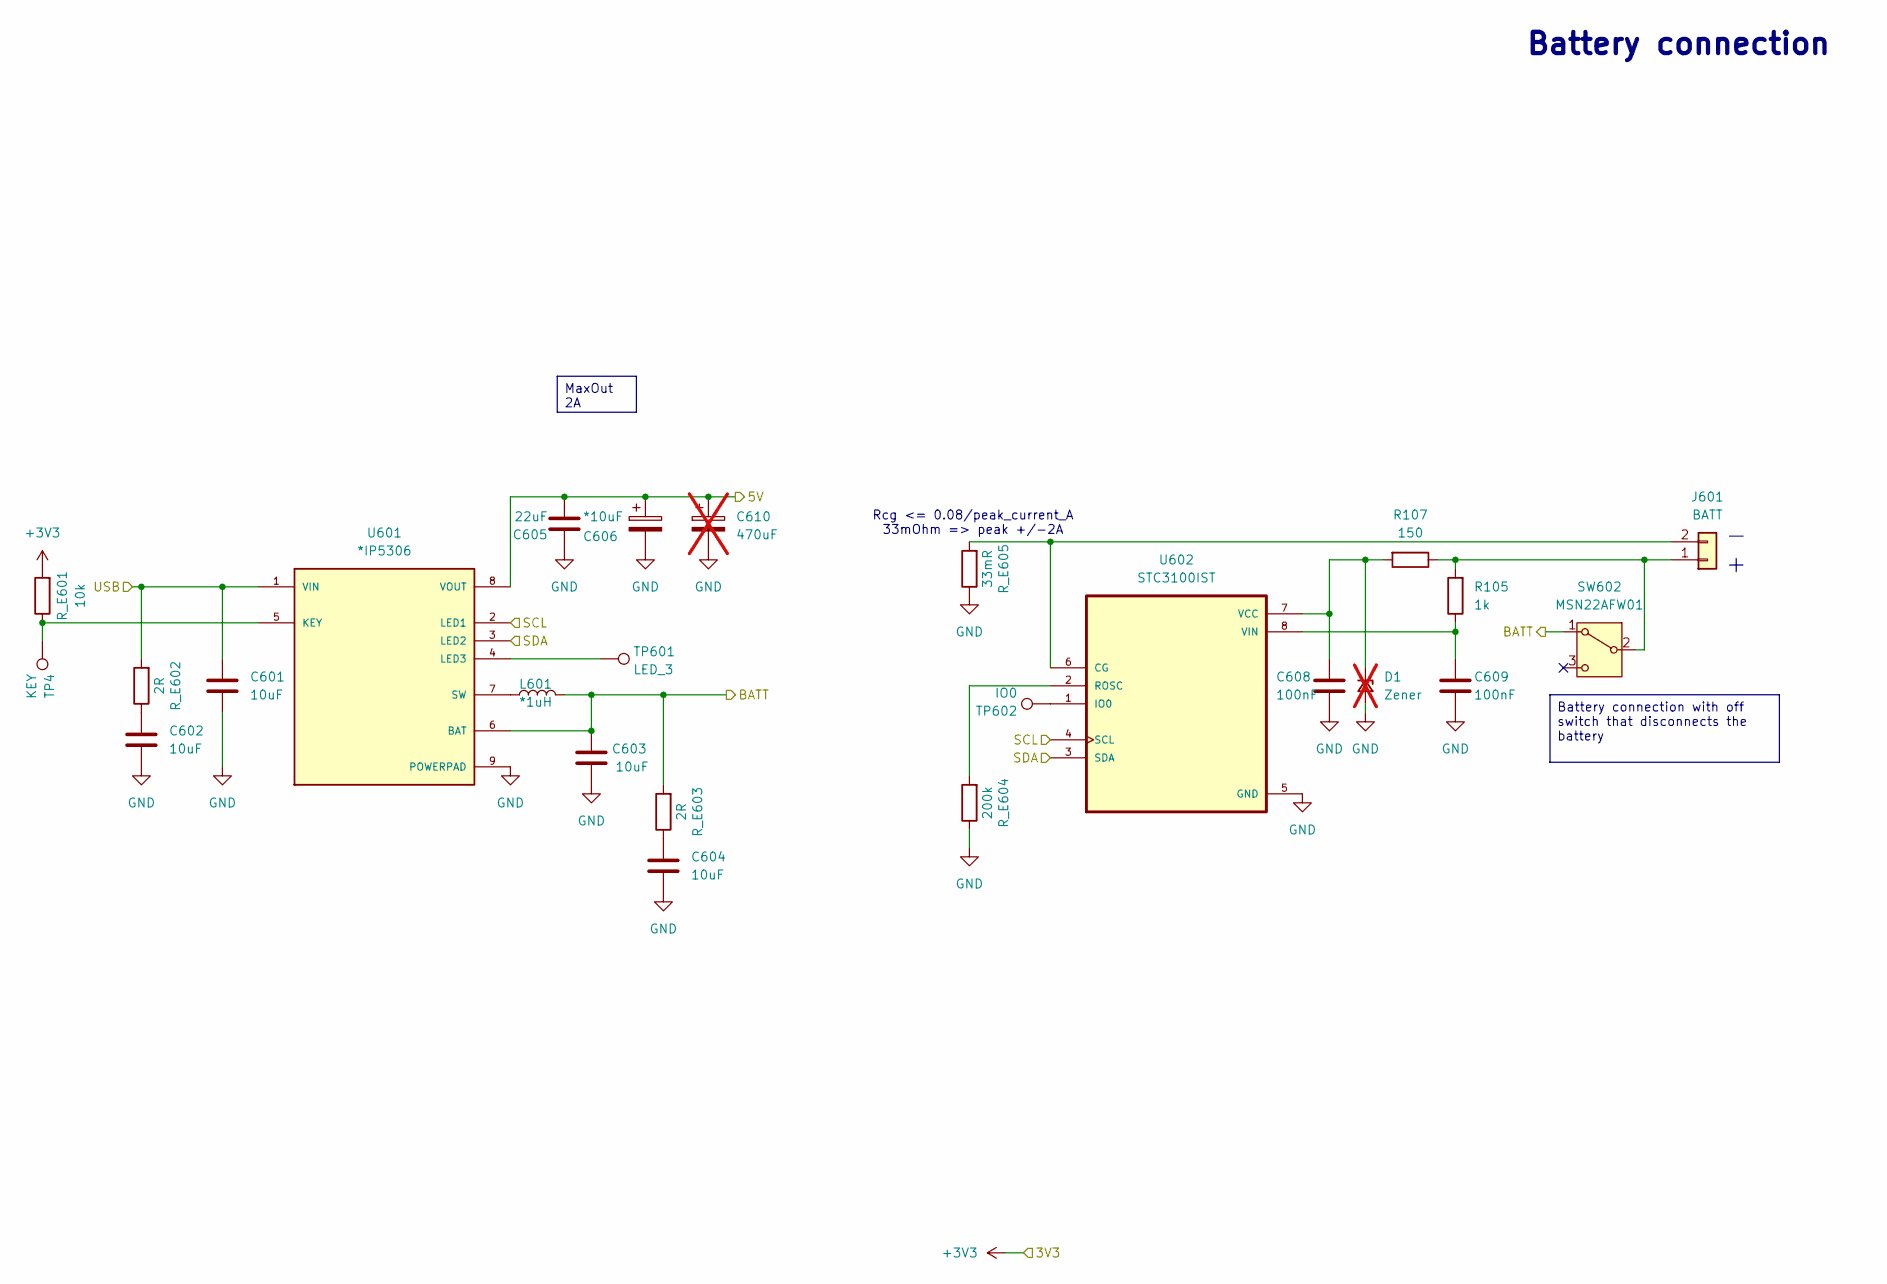
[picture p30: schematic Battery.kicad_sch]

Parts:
C601, C602, C603, C604: 10uF; C_0603_1608Metric_Pad1.08x0.95mm_HandSolder
C605: 22uF; C_0603_1608Metric_Pad1.08x0.95mm_HandSolder
C606: *10uF; CP_EIA-3528-21_Kemet-B_HandSolder
C608, C609: 100nF; C_0603_1608Metric_Pad1.08x0.95mm_HandSolder
C610: 470uF; C_Elec_6.3x7.7; not fitted
D1: Zener; D_SOD-523; not fitted
J601: BATT; Molex_PicoBlade_53398-0271_1x02-1MP_P1.25mm_Vertical
L601: *1uH; L_1008_2520Metric_Pad1.43x2.20mm_HandSolder
R105: 1k; R_0603_1608Metric_Pad0.98x0.95mm_HandSolder
R107: 150; R_0603_1608Metric_Pad0.98x0.95mm_HandSolder
R_E601: 10k; R_0603_1608Metric_Pad0.98x0.95mm_HandSolder
R_E602, R_E603: 2R; R_0603_1608Metric_Pad0.98x0.95mm_HandSolder
R_E604: 200k; R_0603_1608Metric_Pad0.98x0.95mm_HandSolder
R_E605: 33mR; R_0603_1608Metric_Pad0.98x0.95mm_HandSolder
SW602: MSN22AFW01
TP4: KEY; TestPoint_Pad_D1.0mm
TP601: LED_3; TestPoint_Pad_D1.0mm
TP602: IO0; TestPoint_Pad_D1.0mm
U601: *IP5306; SOP127P600X165-9N; PARTREV 1.31
U602: STC3100IST; SOIC65P490X110-8N

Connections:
+3V3: R_E601.2; also elsewhere on the board
+5V: C605.2, C606.1, C610.1, U601.8 (VOUT); also elsewhere on the board
/SCL_3V3: U601.2 (LED1), U602.4 (SCL); also elsewhere on the board
/SDA_3V3: U601.3 (LED2), U602.3 (SDA); also elsewhere on the board
/VBATT: C603.1, L601.2, R_E603.2, SW602.1 (A), U601.6 (BAT); also elsewhere on the board
/VUSB: C601.1, R_E602.2, U601.1 (VIN); also elsewhere on the board
GND: C601.2, C602.2, C603.2, C604.2, C605.1, C606.2, C608.2, C609.2, C610.2, D1.2 (A), R_E604.1, R_E605.1, U601.9 (POWERPAD), U602.5 (GND); also elsewhere on the board
unnamed: C602.1, R_E602.1
unnamed: C604.1, R_E603.1
unnamed: C608.1, D1.1 (K), R107.2, U602.7 (VCC)
unnamed: J601.1, R105.2, R107.1, SW602.2 (B)
unnamed: J601.2, R_E605.2, U602.6 (CG)
unnamed: R_E601.1, TP4.1 (1_1), U601.5 (KEY)
unnamed: TP601.1 (1_1), U601.4 (LED3)
unnamed: L601.1, U601.7 (SW)
unnamed: TP602.1 (1_1), U602.1 (IO0)
unnamed: R_E604.2, U602.2 (ROSC)
unnamed: C609.1, R105.1, U602.8 (VIN)

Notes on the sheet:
- +
Battery connection
Rcg <= 0.08/peak_current_A 33mOhm => peak +/-2A
MaxOut 2A
Battery connection with off switch that disconnects the battery

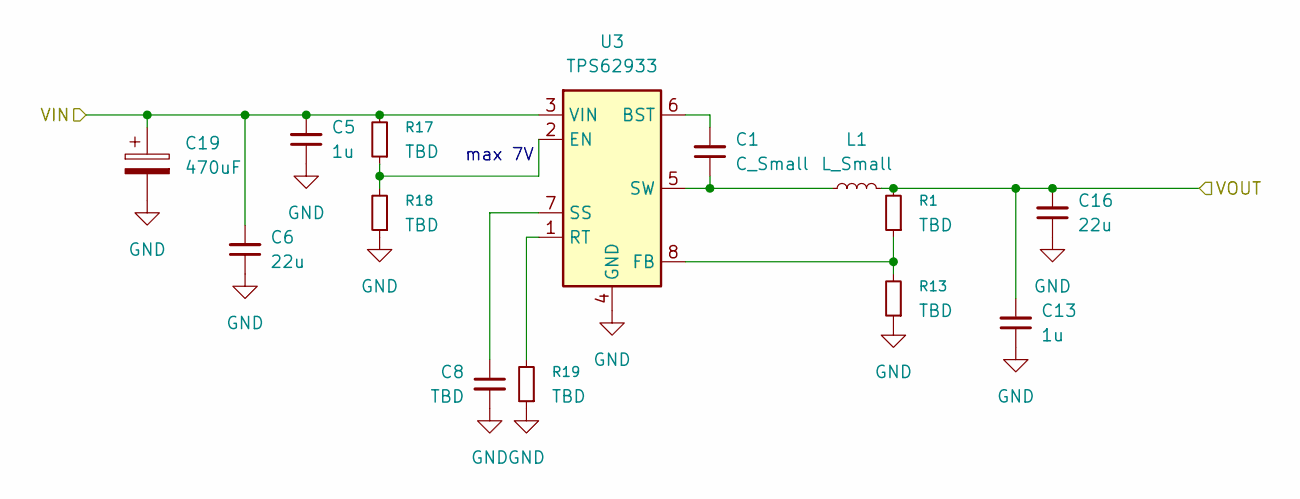
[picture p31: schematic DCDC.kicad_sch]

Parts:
C1: C_Small; C_0603_1608Metric_Pad1.08x0.95mm_HandSolder
C5, C13: 1u; C_0603_1608Metric_Pad1.08x0.95mm_HandSolder
C6, C16: 22u; C_0805_2012Metric_Pad1.18x1.45mm_HandSolder
C8: TBD; C_0603_1608Metric_Pad1.08x0.95mm_HandSolder
C19: 470uF; C_Elec_6.3x7.7
L1: L_Small; L_Wuerth_XHMI-6060
R1, R13, R17, R18, R19: TBD; R_0603_1608Metric_Pad0.98x0.95mm_HandSolder
U3: TPS62933; SOT-583-8

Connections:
+5V: C13.2, C16.2, L1.2, R1.2; also elsewhere on the board
/DCDC/VIN: C5.2, C6.2, C19.1, R17.2, U3.3 (VIN); also elsewhere on the board
GND: C5.1, C6.1, C8.2, C13.1, C16.1, C19.2, R13.1, R18.1, R19.1, U3.4 (GND); also elsewhere on the board
unnamed: C1.2, U3.6 (BST)
unnamed: R17.1, R18.2, U3.2 (EN)
unnamed: R1.1, R13.2, U3.8 (FB)
unnamed: R19.2, U3.1 (RT)
unnamed: C8.1, U3.7 (SS)
unnamed: C1.1, L1.1, U3.5 (SW)

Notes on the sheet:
max 7V

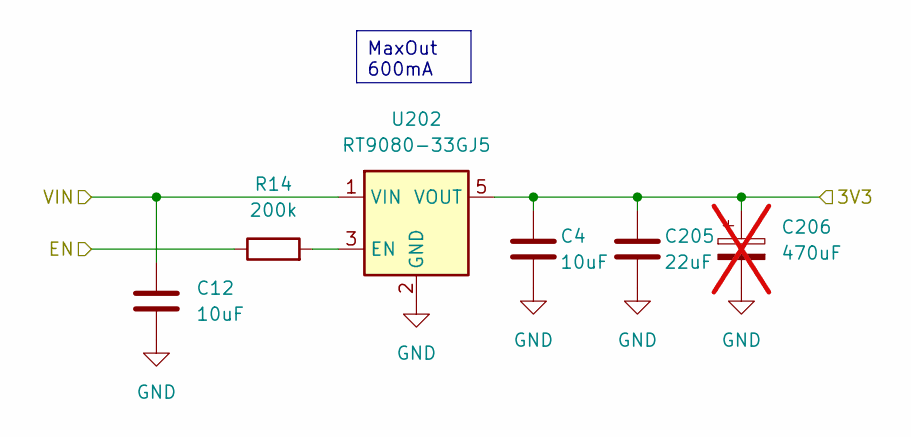
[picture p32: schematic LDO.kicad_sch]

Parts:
C4, C12: 10uF; C_0603_1608Metric_Pad1.08x0.95mm_HandSolder
C205: 22uF; C_0603_1608Metric_Pad1.08x0.95mm_HandSolder
C206: 470uF; C_Elec_6.3x7.7; not fitted
R14: 200k; R_0603_1608Metric_Pad0.98x0.95mm_HandSolder
U202: RT9080-33GJ5; SOT-23-5_HandSoldering

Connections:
+3V3: C4.1, C205.1, C206.1, U202.5 (VOUT); also elsewhere on the board
+5V: C12.1, U202.1 (VIN); also elsewhere on the board
/LDO_EN: R14.1; also elsewhere on the board
GND: C4.2, C12.2, C205.2, C206.2, U202.2 (GND); also elsewhere on the board
unnamed: R14.2, U202.3 (EN)

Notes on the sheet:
MaxOut 600mA

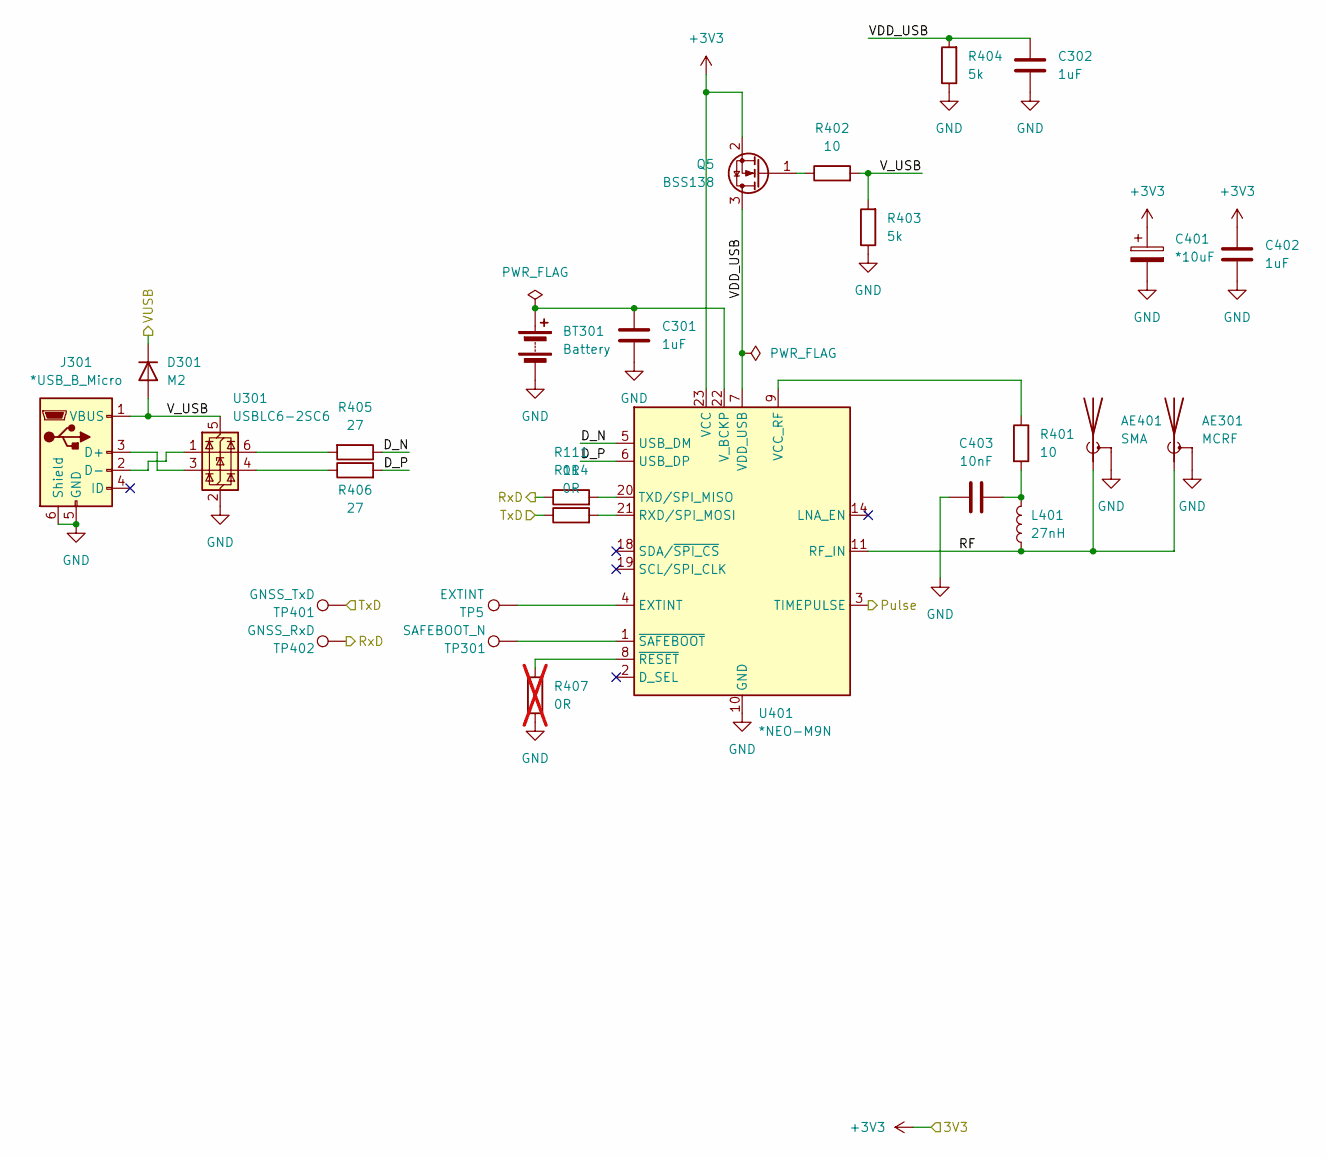
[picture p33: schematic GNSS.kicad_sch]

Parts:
AE301: MCRF; U.FL_Molex_MCRF_73412-0110_Vertical
AE401: SMA; lemo_epb00250ntn
BT301: Battery; BatteryHolder_MPD_BC2003_1x2032
C301, C302, C402: 1uF; C_0603_1608Metric_Pad1.08x0.95mm_HandSolder
C401: *10uF; CP_EIA-3528-21_Kemet-B_HandSolder
C403: 10nF; C_0805_2012Metric_Pad1.18x1.45mm_HandSolder
D301: M2; D_SMA
J301: *USB_B_Micro; 629105150521
L401: 27nH; L_0402_1005Metric_Pad0.77x0.64mm_HandSolder
Q5: BSS138; SOT-23
R111, R114: 0R; R_0603_1608Metric_Pad0.98x0.95mm_HandSolder
R401: 10; R_1206_3216Metric_Pad1.30x1.75mm_HandSolder
R402: 10; R_0603_1608Metric_Pad0.98x0.95mm_HandSolder
R403, R404: 5k; R_0603_1608Metric_Pad0.98x0.95mm_HandSolder
R405, R406: 27; R_0603_1608Metric_Pad0.98x0.95mm_HandSolder
R407: 0R; R_0603_1608Metric_Pad0.98x0.95mm_HandSolder; not fitted
TP5: EXTINT; TestPoint_Pad_D1.0mm
TP301: SAFEBOOT_N; TestPoint_Pad_D1.0mm
TP401: GNSS_TxD; TestPoint_Pad_D1.0mm
TP402: GNSS_RxD; TestPoint_Pad_D1.0mm
U301: USBLC6-2SC6; SOT-23-6
U401: *NEO-M9N; ublox_NEO

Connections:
+3V3: C401.1, C402.1, Q5.2 (S), U401.23 (VCC); also elsewhere on the board
/GNSS/D_N: R405.1, U401.5 (USB_DM)
/GNSS/D_P: R406.2, U401.6 (USB_DP)
/GNSS/RF: AE301.1 (A), AE401.1 (A), L401.1, U401.11 (RF_IN)
/GNSS/VDD_USB: C302.1, Q5.3 (D), R404.2, U401.7 (VDD_USB)
/GNSS/V_USB: D301.2 (A), J301.1 (VBUS), R402.2, R403.2, U301.5 (VBUS)
/GNSS_RxD: R111.1, TP402.1 (1_1); also elsewhere on the board
/GNSS_TxD: R114.1, TP401.1 (1_1); also elsewhere on the board
/Pulse: U401.3 (TIMEPULSE); also elsewhere on the board
/VUSB: D301.1 (K); also elsewhere on the board
GND: AE301.2 (Shield), AE401.2 (Shield), BT301.2 (-), C301.2, C302.2, C401.2, C402.2, C403.1, J301.5 (GND), J301.6 (Shield), R403.1, R404.1, R407.1, U301.2 (GND), U401.10 (GND), U401.12 (GND), U401.13 (GND), U401.24 (GND); also elsewhere on the board
unnamed: BT301.1 (+), C301.1, U401.22 (V_BCKP)
unnamed: C403.2, L401.2, R401.2
unnamed: J301.3 (D+), U301.3 (I/O2)
unnamed: J301.2 (D-), U301.1 (I/O1)
unnamed: Q5.1 (G), R402.1
unnamed: R405.2, U301.6 (I/O1)
unnamed: R406.1, U301.4 (I/O2)
unnamed: TP5.1 (1_1), U401.4 (EXTINT)
unnamed: R114.2, U401.21 (RXD/SPI_MOSI)
unnamed: R111.2, U401.20 (TXD/SPI_MISO)
unnamed: R401.1, U401.9 (VCC_RF)
unnamed: R407.2, U401.8 (~RESET)
unnamed: TP301.1 (1_1), U401.1 (~SAFEBOOT)

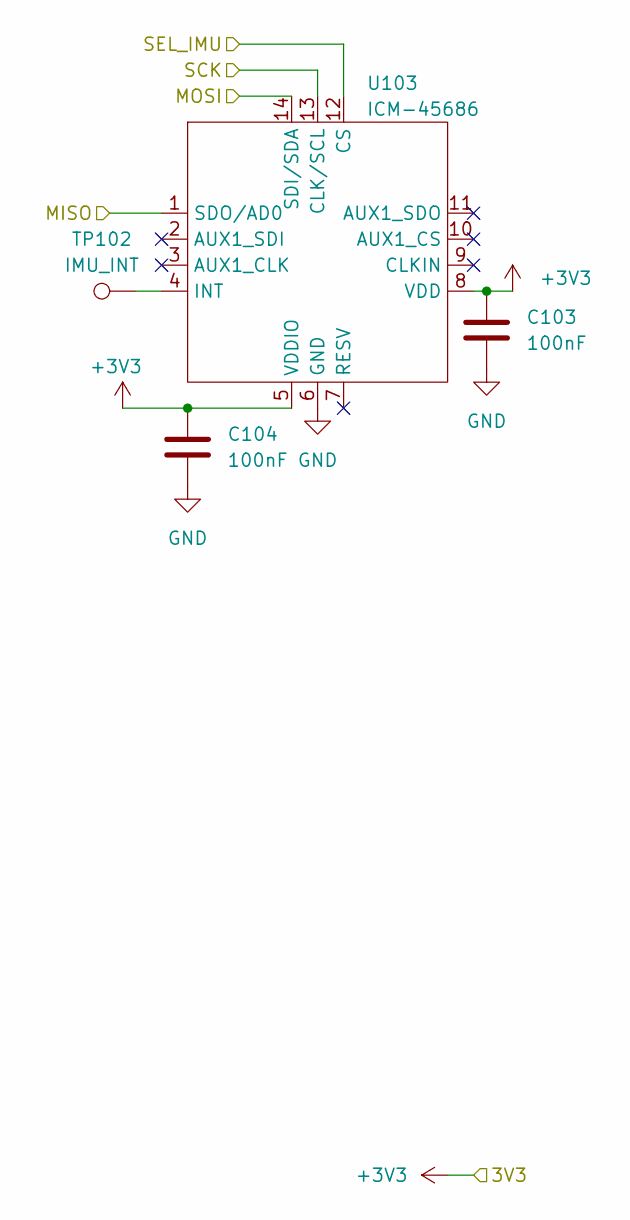
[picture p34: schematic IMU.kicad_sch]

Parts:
C103, C104: 100nF; C_0603_1608Metric_Pad1.08x0.95mm_HandSolder
TP102: IMU_INT; TestPoint_Pad_D1.0mm
U103: ICM-45686; LGA-14_3x2.5mm_P0.5mm_LayoutBorder3x4y

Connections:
+3V3_ESP: C103.2, C104.2, U103.5 (VDDIO), U103.8 (VDD); also elsewhere on the board
/MISO: U103.1 (SDO/AD0); also elsewhere on the board
/MOSI: U103.14 (SDI/SDA); also elsewhere on the board
/SCK: U103.13 (CLK/SCL); also elsewhere on the board
/SEL_IMU: U103.12 (CS); also elsewhere on the board
GND: C103.1, C104.1, U103.6 (GND); also elsewhere on the board

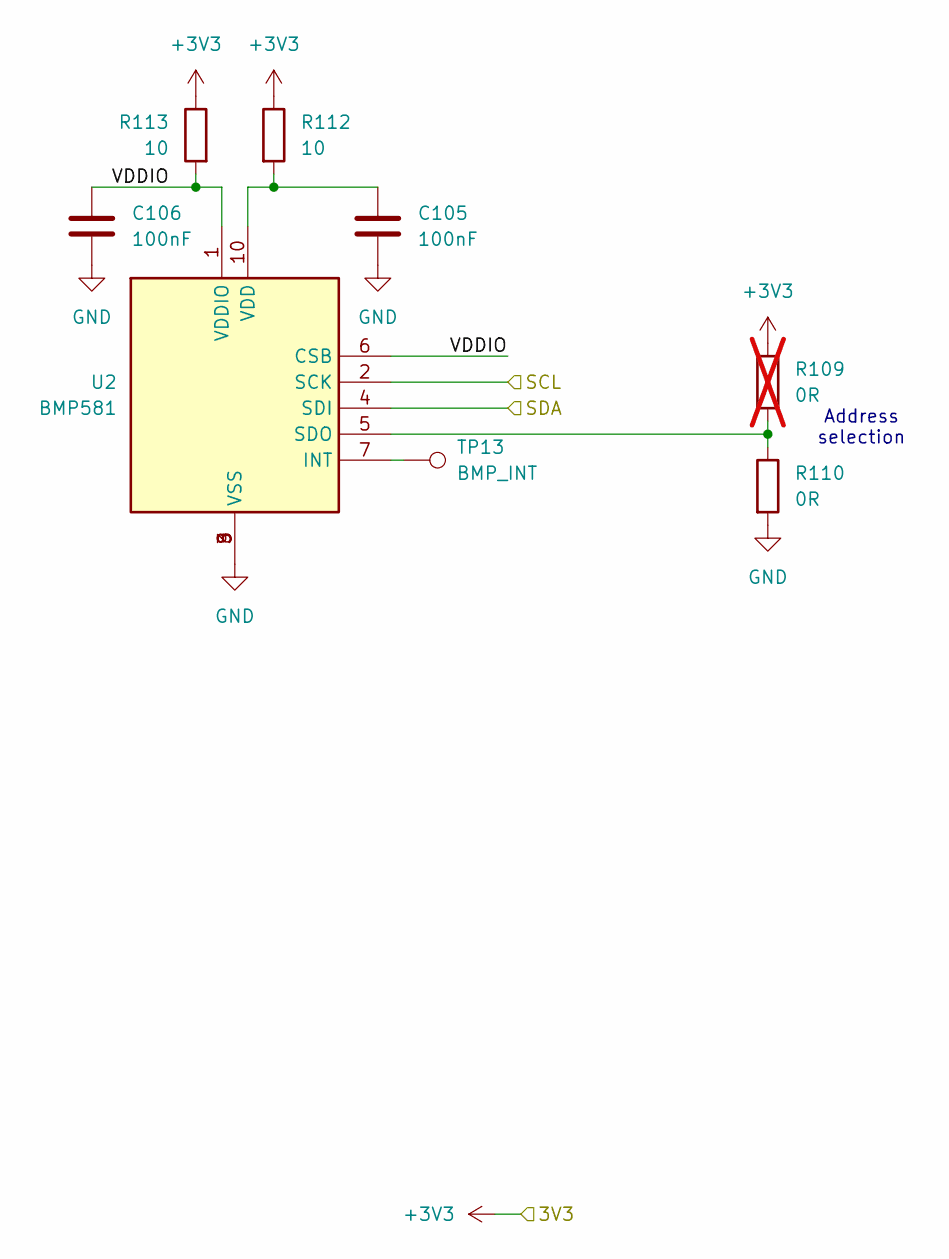
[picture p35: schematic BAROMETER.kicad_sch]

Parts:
C105, C106: 100nF; C_0603_1608Metric_Pad1.08x0.95mm_HandSolder
R109: 0R; R_0603_1608Metric_Pad0.98x0.95mm_HandSolder; not fitted
R110: 0R; R_0603_1608Metric_Pad0.98x0.95mm_HandSolder
R112, R113: 10; R_0603_1608Metric_Pad0.98x0.95mm_HandSolder
TP13: BMP_INT; TestPoint_Pad_D1.0mm
U2: BMP581; Mouser Part Number 262-BMP581

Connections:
+3V3: R109.1, R112.1, R113.1; also elsewhere on the board
/BAROMETER/VDDIO: C106.2, R113.2, U2.1 (VDDIO), U2.6 (CSB)
/SCL_3V3: U2.2 (SCK); also elsewhere on the board
/SDA_3V3: U2.4 (SDI); also elsewhere on the board
GND: C105.1, C106.1, R110.2, U2.3 (VSS), U2.8 (VSS), U2.9 (VSS); also elsewhere on the board
unnamed: TP13.1 (1_1), U2.7 (INT)
unnamed: R109.2, R110.1, U2.5 (SDO)
unnamed: C105.2, R112.2, U2.10 (VDD)

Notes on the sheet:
Address selection

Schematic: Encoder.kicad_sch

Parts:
C701: 100nF; C_0603_1608Metric_Pad1.08x0.95mm_HandSolder
C702, C703: 1nF; C_0603_1608Metric_Pad1.08x0.95mm_HandSolder
R_E701, R_E702, R_E704: 10k; R_0603_1608Metric_Pad0.98x0.95mm_HandSolder
R_E703: 2k; R_0603_1608Metric_Pad0.98x0.95mm_HandSolder
R_E705, R_E706: 47; R_0603_1608Metric_Pad0.98x0.95mm_HandSolder
SW701: *RotaryEncoder; RotaryEncoder_Alps_EC12E-Switch_Vertical_H20mm_CircularMoun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
TP701: CLK; TestPoint_Pad_D1.0mm
TP702: DT; TestPoint_Pad_D1.0mm

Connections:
+3V3: R_E701.2, R_E702.2, R_E704.2; also elsewhere on the board
/CLK: C703.1, R_E702.1, R_E705.1, TP701.1 (1_1); also elsewhere on the board
/DT: C702.1, R_E704.1, R_E706.1, TP702.1 (1_1); also elsewhere on the board
/SW: C701.1, R_E703.2; also elsewhere on the board
GND: C701.2, C702.2, C703.2, SW701.C, SW701.S2; also elsewhere on the board
unnamed: R_E701.1, R_E703.1, SW701.S1
unnamed: R_E705.2, SW701.A
unnamed: R_E706.2, SW701.B

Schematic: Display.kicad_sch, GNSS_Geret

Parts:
C7, C9, C404, C405, C406: 100nF; C_0603_1608Metric_Pad1.08x0.95mm_HandSolder
D8: 1N4148W-G3-08; D_SOD-123
DS1: LTC-4724JF; LTC4724JF; Mouser Part Number 859-LTC-4724JF
R_E103, R_E104, R_E105, R_E106, R_E107, R_E108, R_E109, R_E110: 0R; R_0603_1608Metric_Pad0.98x0.95mm_HandSolder
R_E111, R_E112, R_E113: 39k; R_0603_1608Metric_Pad0.98x0.95mm_HandSolder; not fitted
TP403: RGB_5V; TestPoint_Pad_D1.0mm
U4: *HT16k33; SOIC-28W_7.5x17.9mm_P1.27mm
U5, U6, U7: *7seg_1x1_rgb; 7seg_1x1_rgb
U11: *SN74LV1T34DBVRG4; SOT-23-5
U402: *KW4-804CGB; 7seg_4x1

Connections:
+5V: C7.1, C9.2, C404.2, C405.2, C406.2, U4.28 (VDD), U5.1 (VCC), U6.1 (VCC), U7.1 (VCC), U11.5 (VCC); also elsewhere on the board
/Display/CC1: R_E104.1, U4.6 (COM4)
/Display/CC2: R_E105.1, U4.7 (COM5)
/Display/CC3: R_E106.1, U4.8 (COM6)
/Display/CC11: D8.2 (A), R_E107.2, U4.2 (COM0/AD)
/Display/CC22: R_E108.2, U4.3 (COM1/KS0)
/Display/CC33: R_E109.2, U4.4 (COM2/KS1)
/Display/CC44: R_E110.2, U4.5 (COM3/KS2)
/Display/CCL123: R_E103.2, U4.9 (COM7)
/Display/DP: DS1.6 (ANODE_DP), U4.18 (ROW7/K5), U402.3 (DPX)
/Display/a: DS1.12 (ANODE_AL1), R_E111.1, U4.25 (ROW0/A2), U402.11 (a)
/Display/b: DS1.11 (ANODE_BL2), R_E112.1, U4.24 (ROW1/A1), U402.7 (b)
/Display/c: DS1.3 (ANODE_CL3), R_E113.1, U4.23 (ROW2/A0), U402.4 (c)
/Display/d: DS1.4 (ANODE_D), U4.22 (ROW3/K1), U402.2 (d)
/Display/e: DS1.2 (ANODE_E), U4.21 (ROW4/K2), U402.1 (e)
/Display/f: DS1.15 (ANODE_F), U4.20 (ROW5/K3), U402.10 (f)
/Display/g: DS1.8 (ANODE_G), U4.19 (ROW6/K4), U402.5 (g)
/RGB_DATA: U11.2 (A); also elsewhere on the board
/SCL_5V: U4.26 (SCL); also elsewhere on the board
/SDA_5V: U4.27 (SDA); also elsewhere on the board
GND: C7.2, C9.1, C404.1, C405.1, C406.1, U4.1 (VSS), U5.3 (GND), U6.3 (GND), U7.3 (GND), U11.3 (GND); also elsewhere on the board
unnamed: D8.1 (K), R_E111.2, R_E112.2, R_E113.2
unnamed: DS1.1 (COMMON_CATHODE_DIGIT_1), R_E104.2
unnamed: DS1.5 (COMMON_CATHODE_DIGIT_2), R_E105.2
unnamed: DS1.7 (COMMON_CATHODE_DIGIT_3), R_E106.2
unnamed: DS1.14 (COMMON_CATHODE__L1L2L3), R_E103.1
unnamed: U5.5 (DO), U6.2 (DI)
unnamed: U6.5 (DO), U7.2 (DI)
unnamed: TP403.1 (1_1), U5.2 (DI), U11.4 (Y)
unnamed: R_E107.1, U402.12 (CC1)
unnamed: R_E108.1, U402.9 (CC2)
unnamed: R_E109.1, U402.8 (CC3)
unnamed: R_E110.1, U402.6 (CC4)

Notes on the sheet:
RGB 7seg displays
7seg displays and 7seg driver
ROW+ anode COM- cathode

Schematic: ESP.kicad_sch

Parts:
C2, C14, C15: 100nF; C_0603_1608Metric_Pad1.08x0.95mm_HandSolder
C3, C11, C204: 10uF; C_0603_1608Metric_Pad1.08x0.95mm_HandSolder
C201: 22uF; C_0603_1608Metric_Pad1.08x0.95mm_HandSolder
C202: 470uF; C_Elec_6.3x7.7; not fitted
C203: 1uF; C_0603_1608Metric_Pad1.08x0.95mm_HandSolder
D3, D4: M2; D_SMA
D6, D7: 1N4148W-G3-08; D_SOD-123
D201: LED; LED_D3.0mm
J202: USB4145-03-0230-C; USB4145030230C; Manufacturer_Part_Number USB4145-03-0230-C
Q1: IRLML5203; SOT-23
Q2, Q3: S8050; SOT-23-3
R2, R15: 220; R_0603_1608Metric_Pad0.98x0.95mm_HandSolder
R9, R12, R20, R203: 10k; R_0603_1608Metric_Pad0.98x0.95mm_HandSolder
R10, R16: 2k; R_0603_1608Metric_Pad0.98x0.95mm_HandSolder
R11: 200k; R_0603_1608Metric_Pad0.98x0.95mm_HandSolder
R108: 1k; R_0603_1608Metric_Pad0.98x0.95mm_HandSolder
R202: Manual rst; R_0603_1608Metric_Pad0.98x0.95mm_HandSolder; not fitted
R204, R205: 5k1; R_0603_1608Metric_Pad0.98x0.95mm_HandSolder
SW2: PTS647SN70SMTR2N LFS; SW_SPST_PTS647_Sx38
TP8: +3V3_ESP; TestPoint_Pad_D1.0mm
TP201: FLED; TestPoint_Pad_D1.0mm
TP202: LDO_VCC; TestPoint_Pad_D1.0mm
U1: ESP32-WROOM-32UE
U14: *CH340K; SSOP-10-1EP_3.9x4.9mm_P1mm_EP2.1x3.3mm
U201: RT9080-33GJ5; SOT-23-5_HandSoldering

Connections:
+3V3_ESP: C2.1, C3.1, C201.1, C202.1, C203.1, C204.1, R9.1, R108.2, R203.1, TP8.1 (1_1), U1.2 (VDD), U201.5 (VOUT); also elsewhere on the board
/CLK: U1.11 (IO26); also elsewhere on the board
/DT: U1.12 (IO27); also elsewhere on the board
/ESP/DTR: Q3.1 (E), R20.2, U14.4 (~DTR)
/ESP/D_N: J202.A7 (DN1), J202.B7 (DN2), U14.2 (UD-)
/ESP/D_P: J202.A6 (DP1), J202.B6 (DP2), U14.1 (UD+)
/ESP/IO0: D7.2 (A), U1.25 (IO0)
/ESP/IO2: R10.1, TP201.1 (1_1), U1.24 (IO2)
/ESP/IO12: U1.14 (IO12); also elsewhere on the board
/ESP/IO15: R2.1, U1.23 (IO15)
/ESP/RST: D6.2 (A), R9.2, R202.1, U1.3 (EN)
/ESP/RTS: Q2.1 (E), Q3.2 (B), U14.6 (~RTS)
/ESP/RxD0: U1.34 (RXD0/IO3), U14.9 (RXD)
/ESP/TxD0: R15.1, U1.35 (TXD0/IO1)
/ESP/VCC: C11.1, D3.1 (K), D4.1 (K), Q1.2 (S), R11.1, TP202.1 (1_1), U201.1 (VIN)
/GNSS_RxD: U1.28 (IO17); also elsewhere on the board
/GNSS_TxD: U1.27 (IO16); also elsewhere on the board
/LDO_EN: U1.9 (IO33); also elsewhere on the board
/LIGHT_SENS: U1.7 (IO35); also elsewhere on the board
/MISO: U1.31 (IO19); also elsewhere on the board
/MOSI: U1.37 (IO23); also elsewhere on the board
/Pulse: U1.13 (IO14); also elsewhere on the board
/RGB_DATA: U1.16 (IO13); also elsewhere on the board
/SCK: U1.30 (IO18); also elsewhere on the board
/SCL_3V3: U1.36 (IO22); also elsewhere on the board
/SDA_3V3: U1.33 (IO21); also elsewhere on the board
/SEL_FL: U1.26 (IO4); also elsewhere on the board
/SEL_IMU: U1.8 (IO32); also elsewhere on the board
/SW: U1.10 (IO25); also elsewhere on the board
/VBATT: Q1.3 (D); also elsewhere on the board
/VUSB: C14.1, D3.2 (A), D4.2 (A), J202.A4 (VBUS_1), J202.A9 (VBUS_2), J202.B4 (VBUS_3), J202.B9 (VBUS_4), Q1.1 (G), R12.2, U14.7 (VCC); also elsewhere on the board
GND: C2.2, C3.2, C11.2, C14.2, C15.2, C201.2, C202.2, C203.2, C204.2, D201.1 (K), J202.A1 (GND_1), J202.A8 (SBU1), J202.A12 (GND_2), J202.B1 (GND_3), J202.B8 (SBU2), J202.B12 (GND_4), J202.MH1 (MH5), J202.MH2 (MH6), J202.MH3, J202.MH4, R12.1, R202.2, R204.2, R205.1, SW2.2, U1.1 (GND), U1.15 (GND), U1.38 (GND), U1.39 (GND), U14.3 (GND), U14.11 (GND), U201.2 (GND); also elsewhere on the board
unnamed: D6.1 (K), Q2.3 (C)
unnamed: D7.1 (K), Q3.3 (C)
unnamed: D201.2 (A), R10.2
unnamed: J202.A5 (CC1), R204.1
unnamed: J202.B5 (CC2), R205.2
unnamed: Q2.2 (B), R20.1
unnamed: R2.2, R203.2, SW2.1
unnamed: R108.1, U1.29 (IO5)
unnamed: R15.2, R16.2, U14.8 (TXD)
unnamed: C15.1, R16.1, U14.10 (V3)
unnamed: R11.2, U201.3 (EN)

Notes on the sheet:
LDO_EN
ENC CLK
SEL_IMU
RTS
SCK MISO SDA SCL MOSI
ENC DT
GNSS TX
PULSE
LIGHT_SENS
RGB_DATA
SEL_FL
TP12
SW2
ENC SW
IMU_INT
GNSSRX
LED
https://www.tme.eu/cz/details/usb4145-03-0230-c/konektory-usb-a-ieee1394/gct/
MaxOut 600mA
Manual rst possible by shorting R202
Pins GPIO6 to GPIO11 are connected to the integrated SPI flash integrated on the module and are not recommended for other uses. IO5, 14, 15 are active HIGH at boot IO0, 5, 15 must be HI at boot IO2, 12 must be LO at boot

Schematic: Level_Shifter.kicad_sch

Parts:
C10: 100nF; C_0603_1608Metric_Pad1.08x0.95mm_HandSolder
R3, R4, R5, R6: 10k; R_0603_1608Metric_Pad0.98x0.95mm_HandSolder
RS1: 200k; R_0603_1608Metric_Pad0.98x0.95mm_HandSolder
U9: *TCA39306DDFR; SOT-23-8

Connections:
+3V3: R3.1, R4.1, U9.2 (VREF1); also elsewhere on the board
+5V: R5.1, R6.1, RS1.1; also elsewhere on the board
/SCL_3V3: R3.2, U9.3 (SCL1); also elsewhere on the board
/SCL_5V: R6.2, U9.6 (SCL2); also elsewhere on the board
/SDA_3V3: R4.2, U9.4 (SDA1); also elsewhere on the board
/SDA_5V: R5.2, U9.5 (SDA2); also elsewhere on the board
GND: C10.1, U9.1 (GND); also elsewhere on the board
unnamed: C10.2, RS1.2, U9.7 (VREF2), U9.8 (EN)

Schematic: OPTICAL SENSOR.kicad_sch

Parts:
C107: 100nF; C_0603_1608Metric_Pad1.08x0.95mm_HandSolder
IC1: OPT3001DNPR; SON65P200X200X65-7N-D; Mouser Part Number 595-OPT3001DNPR
R7, R8: 10k; R_0603_1608Metric_Pad0.98x0.95mm_HandSolder
TP14: OPT_INT; TestPoint_Pad_D1.0mm

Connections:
+3V3: C107.2, IC1.1 (VDD), R7.1, R8.1; also elsewhere on the board
/SCL_3V3: IC1.4 (SCL), R8.2; also elsewhere on the board
/SDA_3V3: IC1.6 (SDA), R7.2; also elsewhere on the board
GND: C107.1, IC1.2 (ADDR), IC1.3 (GND), IC1.7 (EP); also elsewhere on the board
unnamed: IC1.5 (INT), TP14.1 (1_1)

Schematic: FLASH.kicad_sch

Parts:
C101: 100nF; C_0603_1608Metric_Pad1.08x0.95mm_HandSolder
R_E101, R_E102: 10k; R_0603_1608Metric_Pad0.98x0.95mm_HandSolder
U102: W25N02KVZEIR; WSON-8-1EP_8x6mm_P1.27mm_EP3.4x4.3mm

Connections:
+3V3: C101.2, R_E101.1, R_E102.2, U102.8 (VCC); also elsewhere on the board
/MISO: U102.2 (DO(IO1)); also elsewhere on the board
/MOSI: U102.5 (DI(IO0)); also elsewhere on the board
/SCK: U102.6 (CLK); also elsewhere on the board
/SEL_FL: U102.1 (~CS); also elsewhere on the board
GND: C101.1, U102.4 (GND); also elsewhere on the board
unnamed: R_E102.1, U102.3 (IO2)
unnamed: R_E101.2, U102.7 (IO3)

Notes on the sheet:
connected to ESP or PULL UP

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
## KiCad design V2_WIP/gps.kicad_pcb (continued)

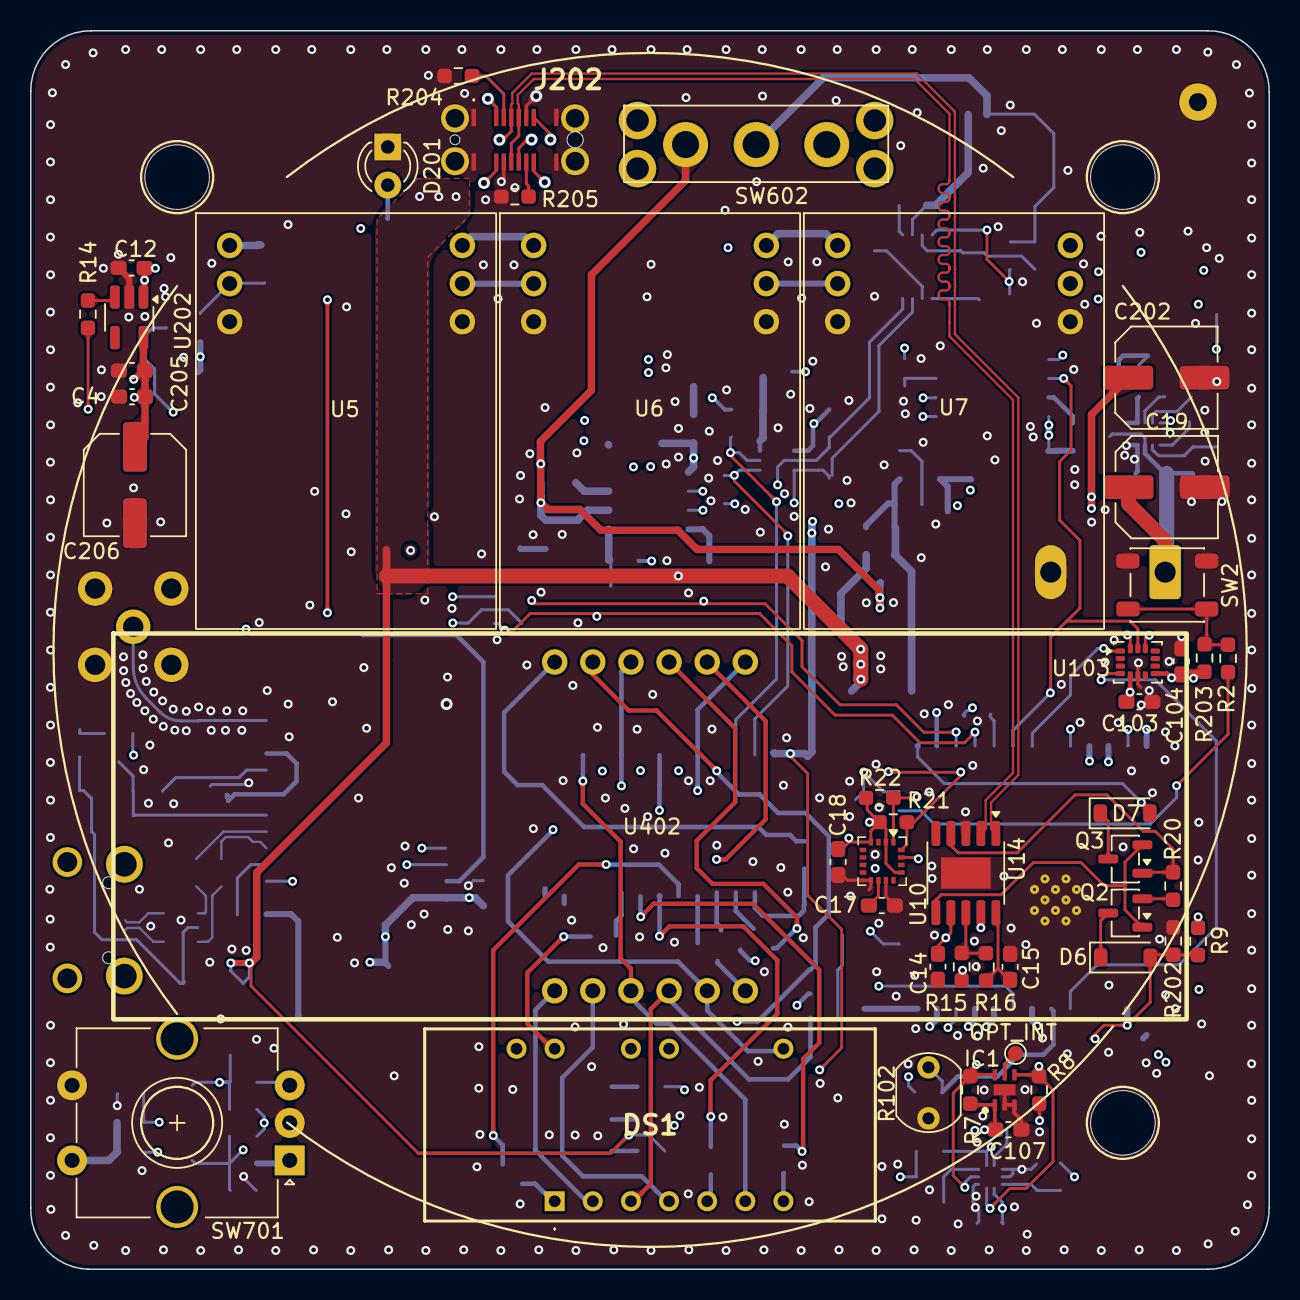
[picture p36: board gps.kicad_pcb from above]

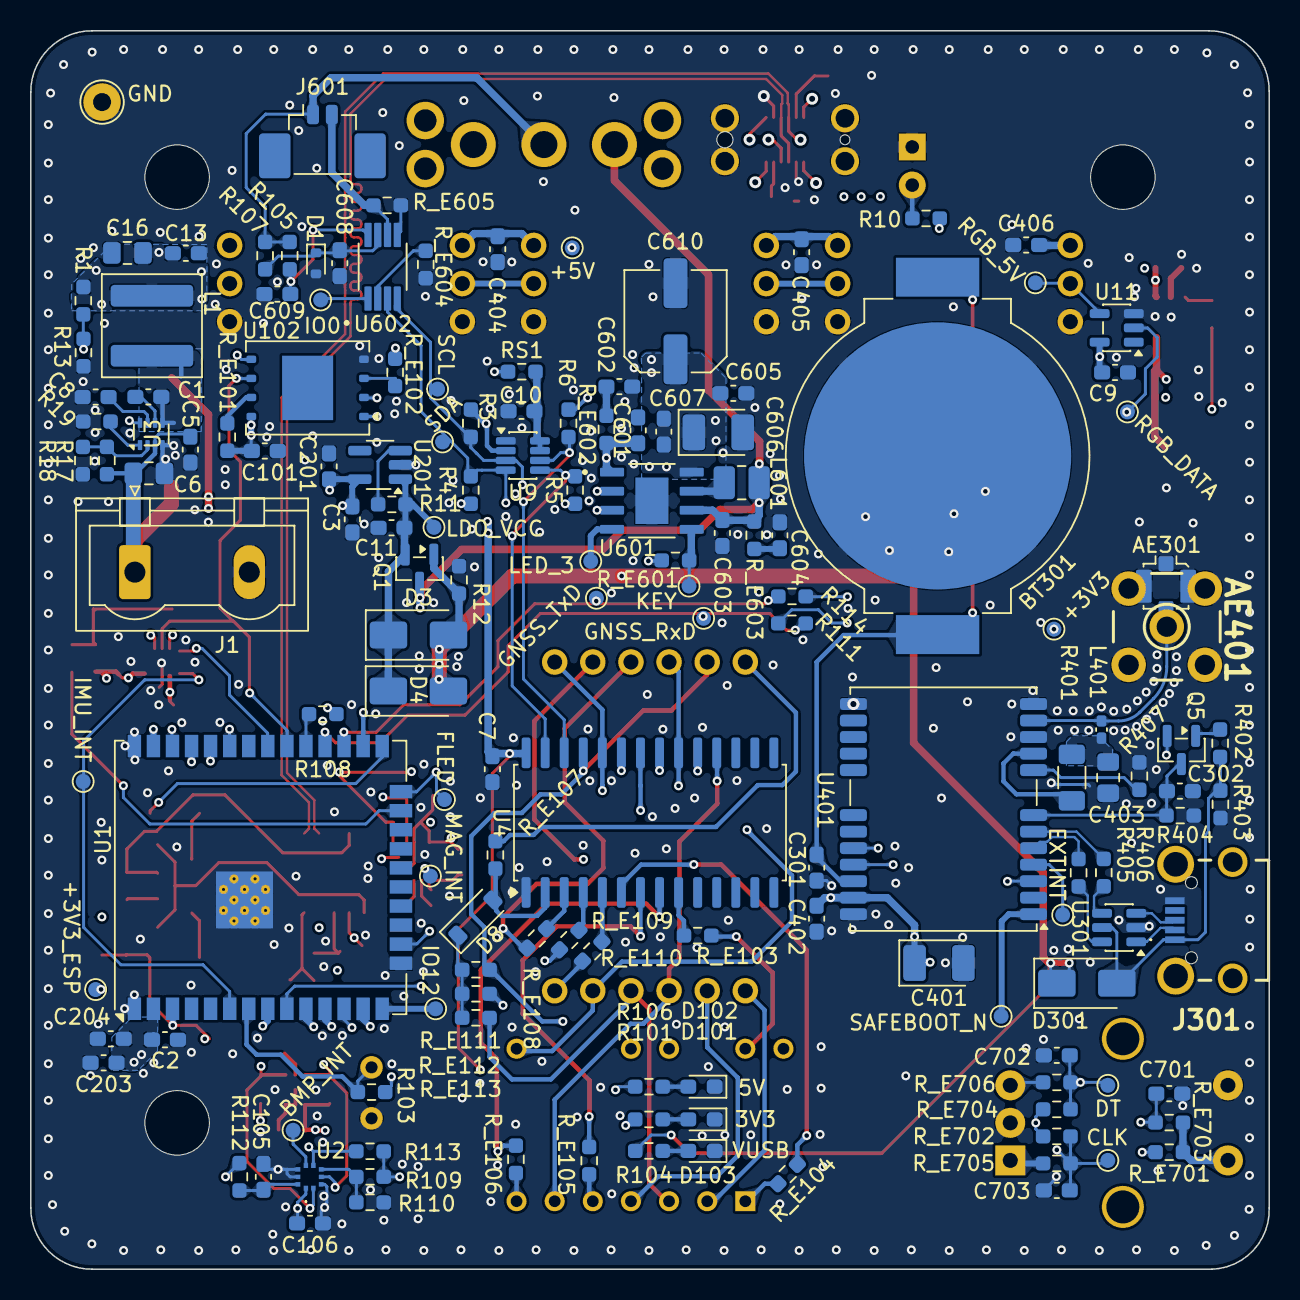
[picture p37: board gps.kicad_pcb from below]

Board: 6 copper layers, 82.5 x 82.5 mm, 198 parts (150 on the bottom side), 129 nets.

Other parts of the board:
C607: 22u; C_0603_1608Metric_Pad1.08x0.95mm_HandSolder

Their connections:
+5V: C607.1, C607.2; also elsewhere on the board

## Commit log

2024-07-19 pcb update
    [gps.kicad_pcb]
2024-07-19 update pcd/sch
    [Display.kicad_sch, ESP.kicad_sch, gps.kicad_pcb]
2024-07-19 update pcb/housing
    [RGB-7seg.FCStd, RGB-7seg.step, gps.kicad_pcb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]
2024-07-27 changed eeprom > 5V, RF antenna track corrected to 50ohm
    [RTC.kicad_sch, gps.kicad_pcb]
2024-07-27 added missing i2c connection
    [Display.kicad_sch, gps.kicad_pcb]
2024-07-27 added level shifters for i2C and RGB displey,
    [Display.kicad_sch, ESP.kicad_sch, RTC.kicad_sch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]
2024-07-27 added pullup for 3V3 i2c
    [ESP.kicad_sch, RTC.kicad_sch, gps.kicad_pcb]
2024-07-28 PCB - adjusted connectors to be inside circle (User.1)
    [gps.kicad_pcb]
2024-07-28 PCB - reworked mouse-bites
    [gps.kicad_pcb]
2024-07-28 added gerbers
    [ESP.kicad_sch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]
2024-08-01 Final V1, cleaned display connections
    [Display.kicad_sch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]
2024-08-04 cleaned schematic
    [Display.kicad_sch, ESP.kicad_sch, RTC.kicad_sch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]
2024-08-05 updated pdf/
    [Display.kicad_sch, ESP.kicad_sch, gps.kicad_pcb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]
2024-08-06 pdf/ added fabs
    [gps.kicad_pcb]
2024-08-06 updated bom
    [gpsBOM.xlsx]
2024-08-14 added 3D_Print/ with front panel models
    [front_panel.stl, gps.step, mount.FCStd]
2024-08-14 added images, separated 3D_Print/ into folders
    [10118192-0001LF.step, 1769.stp, Display.kicad_sch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]
2024-08-14 Update README.md
    added image of board
2024-08-15 3D_Print/ added 10.5mm version of front_panel.stl
    [front_panel_10.5mm.stl, front_panel_10mm.stl]
2024-08-15 3D_Print/ changed 10.5mm version of front_panel.stl to 9.5mm
    [front_panel_9.5mm.stl, mount.FCStd]
2024-08-16 /images/ added board4.png; updated /README.md
2025-06-15 -Deleted backups for V1 -Cloned V1 into V2 -V2/ added USB interface for GNSS -V2/ mergo into 1 board -V2/ Switched to a 6 layer board
    [10118192-0001LF.step, 1769.stp, Display.kicad_sch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]
2025-06-17 minor schematic changes
    [Display.kicad_sch, GNSS.kicad_sch, gps.kicad_sch]
2025-06-17 switched esp modul symbol for esp sheet
    [GNSS.kicad_sch, Level_Shifter.kicad_sch, gps.kicad_pcb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]
2025-06-19 added LED indicators, light sensor, changed to CC 7seg displays
    [Display.kicad_sch, ESP.kicad_sch, GNSS.kicad_sch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]
2025-06-19 added battery monitoring circuits
    [Battery.kicad_sch, GNSS.kicad_sch, IP5306.step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]
2025-06-20 added FLASH module; moved encoder into separate schematic
    [Battery.kicad_sch, ESP.kicad_sch, Encoder.kicad_sch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]
2025-06-21 added USB, button
    [Battery.kicad_sch, Display.kicad_sch, ESP.kicad_sch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]
2025-06-22 fixed errors in schematic
    [Battery.kicad_sch, ESP.kicad_sch, Encoder.kicad_sch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]
2025-06-22 schematic tweaks
    [ESP.kicad_sch, gps.kicad_pcb]
2025-06-29 Removed EEPROM, Adjusted Flash connection, renamed ESP pins and several other signals
    [Battery.kicad_sch, Display.kicad_sch, ESP.kicad_sch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]
2025-07-08 minor changes
    [Battery.kicad_sch, ESP.kicad_sch, GNSS.kicad_sch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]
2025-08-01 finallizes schematic; pcb progress
    [Battery.kicad_sch, Display.kicad_sch, ESP.kicad_sch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]
2025-08-05 updated most datashets
    [Battery.kicad_sch, Display.kicad_sch, ESP.kicad_sch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]
2026-03-06 up to date i dont remember what changed
    [Battery.kicad_sch, Display.kicad_sch, ESP.kicad_sch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]
2026-07-01 updated list of changes in README.md
    [629105150521.stp, BMP581.stp, Battery.kicad_sch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]
2026-07-01 updated read me, deleted duplicate unused files
    [board.stl, front_panel_10.5mm.stl, front_panel_10mm.stl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]
2026-07-04 changed footprints of U102 and U602
    [Battery.kicad_sch, gps.kicad_pcb, gps.kicad_sch]
2026-07-04 reworked the schematic, changed differential pairs and RF traces, small PCB adjustments
    [BAROMETER.kicad_sch, Battery.kicad_sch, Display.kicad_sch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]
2026-07-04 added second LDO
    [ESP.kicad_sch, LDO.kicad_sch, gps.kicad_pcb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]
2026-07-06 switched Tx and Rx on GNSS module, added option to switch them, minor pcb changes
    [ESP.kicad_sch, GNSS.kicad_sch, gps.kicad_pcb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]
2026-07-08 adjusted elec capacitors
    [Battery.kicad_sch, ESP.kicad_sch, LDO.kicad_sch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]
2026-07-10 added 24 to 5V DCDC
    [gps.kicad_pcb, gps.kicad_sch]
2026-07-13 added magnetometer
    [MAGNETOMETER.kicad_sch, gps.kicad_pcb, gps.kicad_sch]
2026-07-15 moved DCDC to its sheet, added elec capacitor to DCDC
    [DCDC.kicad_sch, gps.kicad_pcb, gps.kicad_sch]

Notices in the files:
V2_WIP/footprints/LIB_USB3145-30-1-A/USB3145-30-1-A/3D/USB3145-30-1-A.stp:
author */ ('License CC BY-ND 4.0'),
